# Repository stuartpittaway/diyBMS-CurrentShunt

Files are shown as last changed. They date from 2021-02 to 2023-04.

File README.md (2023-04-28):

# diyBMS Current Monitor

Isolated current, voltage and amp hour counting monitor for battery banks up to 85 volt.

Designed for use with the diyBMS controller, although can be operated standalone using RS485 and MODBUS

The MODBUS register list is [here](./Code/diybmsCurrentShunt/MODBUS%20Registers.md)

# Videos on how to use and build

[YouTube playlist](https://youtube.com/playlist?list=PLHhwQCDPuRcZW3u0jJucsiCCsUbNbMy-c) for DIYBMS videos

# Support

If you find the BMS useful, please consider buying me a beer, check out Patron for more information

https://patreon.com/StuartP

Forum:
https://community.openenergymonitor.org/c/hardware/diybms/53

# HARDWARE

This repository contains the hardware designs, generally in KiCad format.  Unless you are changing the design, you don't need to use/install KiCad, just use the premade files.

The GERBER files are in the [export folder](CurrentShuntCircuit/export), along with the files for JLCPCB assembly service.  You need to request the BOTTOM of the board to be assembled!!

* [current_monitor_gerbers.zip](../../raw/master/CurrentShuntCircuit/export/current_monitor_gerbers.zip)
* [CurrentShuntCircuit_bom_jlc.csv](../../raw/master/CurrentShuntCircuit/export/CurrentShuntCircuit_bom_jlc.csv)
* [CurrentShuntCircuit_cpl_jlc.csv](../../raw/master/CurrentShuntCircuit/export/CurrentShuntCircuit_cpl_jlc.csv)

If you use this coupon code when you place a JLCPCB order

JLC-Stuart

and this link

https://jlcpcb.com/RSZ

you will get a discount and I get a very small amount of credit for every 30 orders, which helps to support the cost of prototyping new designs and adding new features.

Gerber and BOM files are automatically generated when changes are made to the design and pushed into GITHUB.

The bill of materials (BOM) is [here](./CurrentShuntCircuit/export/CurrentShuntCircuit-bom.csv)

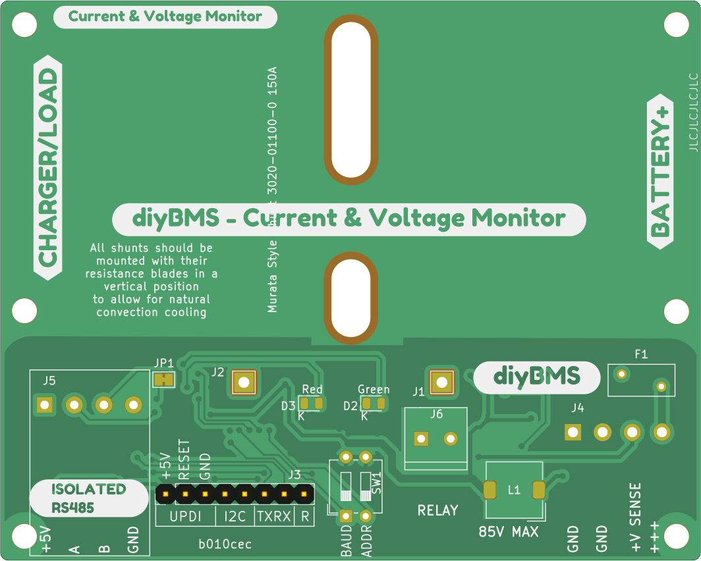
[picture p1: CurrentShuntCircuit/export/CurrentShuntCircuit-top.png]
top


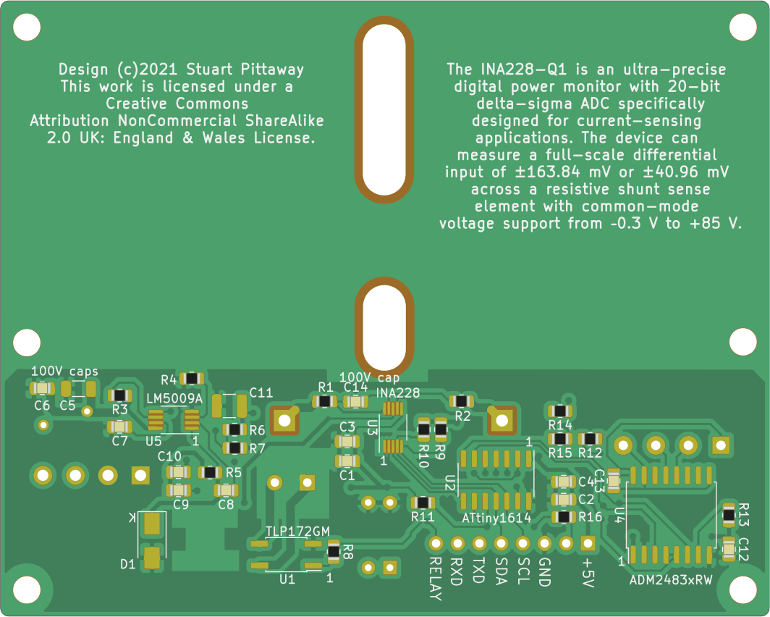
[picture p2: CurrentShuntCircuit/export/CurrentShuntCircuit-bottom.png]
bottom


## Texas Instruments

### INA228 (current sensor)
https://www.ti.com/product/INA228

### LM5009A (voltage regulator)
https://www.ti.com/product/LM5009A

## diyBMS Controller Changes

You need to add a "blob" of solder across solder bridge JP4 on the DIYBMS controller to enable RS485 termination resistor.

# SHUNT

The design is based on 50mV shunts, such as the Murata range

* 3020-01100-0 [150A](https://uk.farnell.com/murata-power-solutions/3020-01100-0/dc-shunt-150a-0-05v-screw/dp/2932602)
* 3020-0110X-0 [200A](https://uk.rs-online.com/web/p/shunts/8103277/) or [500A](https://uk.rs-online.com/web/p/shunts/8233570/)

technically, any 50mV shunt can be used, but the PCB is drilled specifically for the footprints of these devices.

Larger rating shunts will work, but won't fit onto the PCB

## PICKING THE CORRECT SHUNT 

Always pick a shunt at least 25% higher rating than you expect your maximum current load to be.

The INA chip uses 40.96mV maximum shunt voltage, so 50mV shunts are ideal for this range.

The maximum shunt current reading is calculated by this formula:

"Total shunt amp rating" * (40.96 / "Shunt mV scale")

For example a 200amp/50mV shunt:

200 * (40.96 / 50) = 163.84amp maximum reading.

# CODE/FIRMWARE



The board uses an ATTINY1614 chip, this requires an UPDI style of programmer, you can use an old Arduino style board to do this.  Take a look at [this](https://www.hackster.io/john-bradnam/create-your-own-updi-programmer-1e55f1) or [this](https://github.com/SpenceKonde/AVR-Guidance/blob/master/UPDI/jtag2updi.md).

Source code is located in the [Code](Code) folder, and requires PLATFORM.IO to compile.

Precompiled versions are available in the [releases](https://github.com/stuartpittaway/diyBMS-CurrentShunt/releases) page.  You use AVRDUDE to program these to the ATTINY chip using an UPDI programmer.

## Programming ATTINY1614

Use the file diyBMSCurrentMonitor_ATtiny1614.hex from the releases section.  This is precompiled for you, so after this all you need to do is use AVRDUDE to program the device.

AVRDUDE can be downloaded from [here](http://savannah.nongnu.org/projects/avrdude)

Change "COM8" to match your environment.  

```
avrdude -v -p attiny1614 -C avrdude.conf -c jtag2updi -b 115200 -P "COM8" -U flash:w:diyBMSCurrentMonitor_ATtiny1614.hex:i
```

# WARNING

This is a DIY product/solution so don’t use this for safety critical systems or in any situation where there could be a risk to life.  

There is no warranty, it may not work as expected or at all.

The use of this project is done so entirely at your own risk.  It may involve electrical voltages which could kill - if in doubt, seek help.

The use of this project may not be compliant with local laws or regulations - if in doubt, seek help.

# License

This work is licensed under a Creative Commons Attribution-NonCommercial-ShareAlike 2.0 UK: England & Wales License.

https://creativecommons.org/licenses/by-nc-sa/2.0/uk/

You are free to:
* Share — copy and redistribute the material in any medium or format
* Adapt — remix, transform, and build upon the material
The licensor cannot revoke these freedoms as long as you follow the license terms.

Under the following terms:
* Attribution — You must give appropriate credit, provide a link to the license, and indicate if changes were made. You may do so in any reasonable manner, but not in any way that suggests the licensor endorses you or your use.
* Non-Commercial — You may not use the material for commercial purposes.
* ShareAlike — If you remix, transform, or build upon the material, you must distribute your contributions under the same license as the original.
* No additional restrictions — You may not apply legal terms or technological measures that legally restrict others from doing anything the license permits.

Notices:
You do not have to comply with the license for elements of the material in the public domain or where your use is permitted by an applicable exception or limitation.

No warranties are given. The license may not give you all of the permissions necessary for your intended use. For example, other rights such as publicity, privacy, or moral rights may limit how you use the material.

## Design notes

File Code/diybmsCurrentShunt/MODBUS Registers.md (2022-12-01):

# Holding Registers (command 3)

Returns 16 bit word value for the following configuration items.  Some items are split over two registers and will need to recombined before use.
For valid results you must read both registers as part of the same request, otherwise invalid/corrupt data will be returned.

All registers are read only, unless also specified in "Write Registers" later on

|Register|Description|
|---|---|
|40001|Voltage (4 byte double)
|40002|Voltage
|40003|Current (4 byte double)
|40004|Current
|40005|milliamphour_out (4 byte unsigned long uint32_t)
|40006|milliamphour_out
|40007|milliamphour_in (4 byte  unsigned long uint32_t)
|40008|milliamphour_in
|40009|temperature (signed int16)
|40010|Various status flags (see below)
|40011|Power (4 byte double)
|40012|Power
|40013|Daily milliamphour_out (4 byte unsigned long uint32_t)
|40014|Daily milliamphour_out (4 byte unsigned long uint32_t)
|40015|Daily milliamphour_in (4 byte  unsigned long uint32_t)
|40016|Daily milliamphour_in
|40017|shunt_resistance (4 byte double)
|40018|shunt_resistance
|40019|shunt_max_current  (unsigned int16)
|40020|shunt_millivolt  (unsigned int16)
|40021|Battery Capacity (ah)  (unsigned int16)
|40022|Fully charged voltage (4 byte double)
|40023|Fully charged voltage
|40024|Tail current (Amps) (4 byte double)
|40025|Tail current (Amps)
|40026|Charge efficiency factor % (unsigned int16) (scale x100 eg. 10000 = 100.00%, 9561 = 95.61%)
|40027|State of charge % (unsigned int16) (scale x100 eg. 10000 = 100.00%, 8012 = 80.12%, 100 = 1.00%)
|40028|INA_REGISTER::SHUNT_CAL (unsigned int16)
|40029|Temperature limit (signed int16)
|40030|Bus Overvoltage (overvoltage protection)(4 byte double)
|40031|Bus Overvoltage (overvoltage protection)
|40032|BusUnderVolt (4 byte double)
|40033|BusUnderVolt
|40034|Shunt Over Voltage Limit (current limit) (4 byte double)
|40035|Shunt Over Voltage Limit (current limit) 
|40036|Shunt UNDER Voltage Limit (under current limit) (4 byte double)
|40037|Shunt UNDER Voltage Limit (under current limit)
|40038|Shunt Over POWER LIMIT (4 byte double)
|40039|Shunt Over POWER LIMIT
|40040|Shunt Temperature Coefficient (SHUNT_TEMPCO) (unsigned int16)
|40041|INAXXX chip model number (should always be 0x0228)
|40042|GITHUB version
|40043|GITHUB version
|40044|COMPILE_DATE_TIME_EPOCH
|40045|COMPILE_DATE_TIME_EPOCH
|40046|Watchdog timer trigger count (like error counter)(unsigned int16)
|40047|DEBUG CONFIG (unsigned int16)
|40048|DEBUG ADC_CONFIG (unsigned int16)
|40049|DEBUG SHUNT_CAL (unsigned int16)
|40050|DEBUG SHUNT_TEMPCO
|40051|DEBUG DIAG_ALRT
|40052|DEBUG SOVL
|40053|DEBUG SUVL
|40054|DEBUG BOVL
|40055|DEBUG BUVL
|40056|DEBUG TEMP_LIMIT
|40057|DEBUG PWR_LIMIT
|40058|DEBUG DIETEMP

# 0x16 Write Multiple Registers

|Register|Description|Example|
|---|---|---|
|40010|Watchdog timer trigger count (like error counter) (unsigned int16)|
|40013|Daily milliamphour_out/reset to zero
|40014|Daily milliamphour_out/reset to zero
|40015|Daily milliamphour_in/reset to zero
|40016|Daily milliamphour_in/reset to zero
|40019|shunt_max_current  (unsigned int16) |e.g. 150
|40020|shunt_millivolt  (unsigned int16) |e.g. 50
|40021/40022|Battery Capacity (ah)  (unsigned int16)
|40023/40024|Fully charged voltage
|40025|Tail current (Amps)
|40026|Charge efficiency factor % (unsigned int16) (scale x100 eg. 10000 = 100.00%, 9561 = 95.61%)
|40028|SHUNT_CAL (unsigned int16) **
|40029|Temperature limit (signed int16)|degrees C)
|40030/40031|Bus Overvoltage (overvoltage protection)(4 byte double)|Volts
|40032/40033|Bus Under Volt (4 byte double) |Volts
|40034/40035|Shunt Over Voltage Limit (current limit) (4 byte double)|Current
|40036/40037|Shunt UNDER Voltage Limit (under current limit) (4 byte double)|Current
|40038/40039|Shunt Over POWER LIMIT (4 byte double)|Power

** For normal configuration, just set the shunt maximum current and millivolt registers.  Shunt_Cal is calculated as needed based on those values.  For fine tuning calibration, the SHUNT_CAL register can be written to/adjusted.  Once a register is set, it is stored in EEPROM and used when shunt is powered up.

# Bit values for Register 40017 (status flags)

Returns a BIT value (on/off) for the following configuration items:

(First byte)
|Bit|Description|Read write|
|---|---|---|
16|TMPOL|Read only
15|SHNTOL|Read only
14|SHNTUL|Read only
13|BUSOL|Read only
12|BUSUL|Read only
11|POL|Read only
10|Temperature compensation enabled|Read write
9|ADC Range 0=±163.84 mV, 1=±40.96 mV (only 40.96mV supported by diyBMS)|Read only

(Second byte)
|Bit|Description|Read write|
|---|---|---|
8|Relay Trigger on TMPOL|Read write
7|Relay Trigger on SHNTOL|Read write
6|Relay Trigger on SHNTUL|Read write
5|Relay Trigger on BUSOL|Read write
4|Relay Trigger on BUSUL|Read write
3|Relay Trigger on POL|Read write
2|Existing Relay state (0=off)|Read write
1|Factory reset bit (always 0 when read)|Read write

Registers 1 to 6 indicate the current alert state of the INA228 chip, zero means not alerted.  The RED LED will light when any of the alert states are non-zero.

Registers 9 to 14 control which alerts will trigger the relay to turn on.  Value of 1 means the alert is active/enabled.

Register 15 returns the current relay state (and allows the relay to be manually controlled - TBC)

Register 16 always returns zero when read (set to 1 to perform a factory reset on the monitor, returning all values to defaults - TBC)

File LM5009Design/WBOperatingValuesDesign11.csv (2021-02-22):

Name | Value | Category | Description
D1 Pd | 29.17 mW | Diode | Output Diode Power Dissipation
Vout | 5 V | System Information | Operational Output Voltage
IC Tolerance | 50 mV | IC | IC Feedback Tolerance
Cin IRMS | 11.93 mA | Capacitor | Input capacitor RMS ripple current
Cin Pd | 504.32 nW | Capacitor | Input capacitor power dissipation
Cout IRMS | 26.37 mA | Capacitor | Output capacitor RMS ripple current
Cout Pd | 2.11 µW | Capacitor | Output capacitor power dissipation
Duty Cycle | 6.06% | System Information | Duty cycle
Frequency | 53.09 kHz | System Information | Switching frequency
IC Tj | 62.2 °C | IC | IC junction temperature
ICThetaJA | 40 °C/W | IC | IC junction-to-ambient thermal resistance
L Ipp | 91.33 mA | Inductor | Peak-to-peak inductor ripple current
L Pd | 7.13 mW | Inductor | Inductor power dissipation
IC Pd | 55.06 mW | IC | IC power dissipation
Pout | 250 mW | System Information | Total output power
Iin Avg | 3.67 mA | IC | Average input current
IC Ipk | 95.67 mA | IC | Peak switch current in IC
Mode | CCM | System Information | Conduction Mode
Vout p-p | 277.38 µV | System Information | Peak-to-peak output ripple voltage
M Vds Act | 15.52 mV | Mosfet | Voltage drop across the MosFET
M Irms | 12.31 mA | Mosfet | MOSFET RMS current
Total Pd | 91.36 mW | Power | Total Power Dissipation
Efficiency | 73.2% | System Information | Steady state efficiency
FootPrint | NA | System Information | Total Foot Print Area of BOM components
D1 Pd | 29.17 mW | Power | Output Diode Power Dissipation
Vin | 85 V | System Information | Vin operating point
Iout | 50 mA | System Information | Iout operating point
Cin Pd | 504.32 nW | Power | Input capacitor power dissipation
Cout Pd | 2.11 µW | Power | Output capacitor power dissipation
L Pd | 7.13 mW | Power | Inductor power dissipation
IC Pd | 55.06 mW | Power | IC power dissipation
BOM Count | 6 | System Information | Total Design BOM count
Vout Actual | 5 V | System Information | Vout Actual calculated based on selected voltage divider resistors
Vout Tolerance | 3.03% | System Information | Vout Tolerance based on IC Tolerance (no load) and voltage divider resistors if applicable
Total BOM | NA | System Information | Total BOM Cost

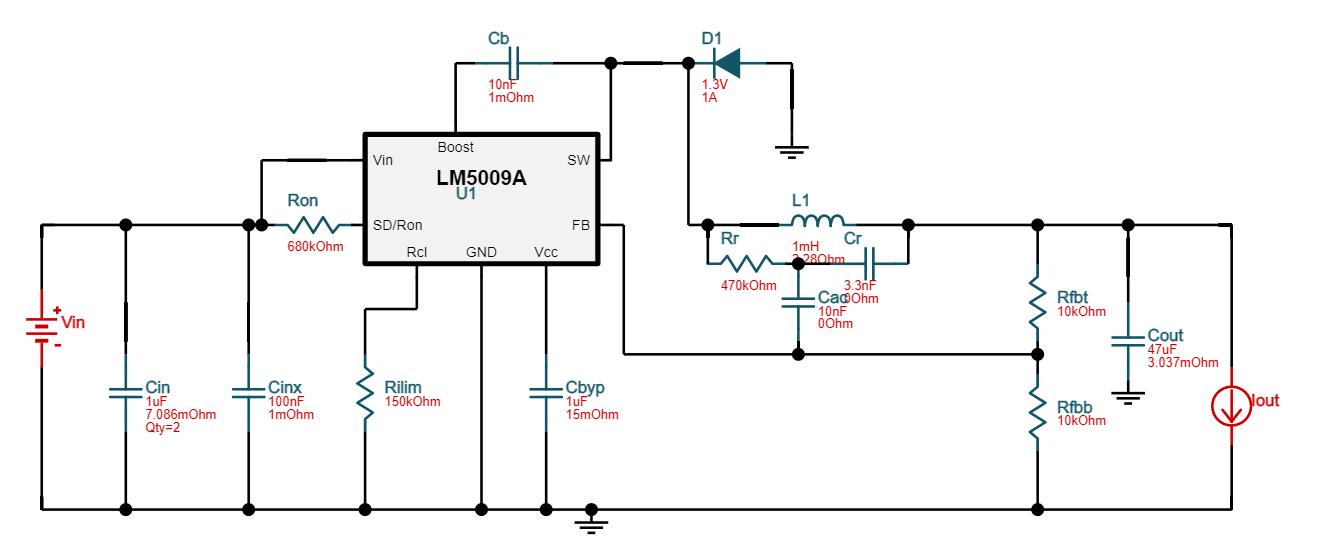
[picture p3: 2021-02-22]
LM5009Design/circuit.png

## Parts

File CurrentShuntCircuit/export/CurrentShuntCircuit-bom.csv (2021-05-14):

Row | Description | Part | References | Value | Footprint | Quantity Per PCB | Status | Datasheet | PartNumber | LCSCStockCode | JLCPCBRotation | JLC
1 | Unpolarized capacitor | C | C10 | 3.3nF | C_0805_2012Metric | 1 |  | ~ | CL21B332KBANNNC | C53175
2 | Unpolarized capacitor | C | C8 C9 | 10nF | C_0805_2012Metric | 2 |  | ~ | CL21B103KBANNNC | C1710
3 | Unpolarized capacitor | C | C3 C4 C12 C13 | 100nF | C_0805_2012Metric | 4 |  |  | CC0805KRX7R9BB104 | C49678
4 | Unpolarized capacitor | C | C1 C2 C7 | 1uF | C_0805_2012Metric | 3 |  | ~ | CL21B105KBFNNNE | C28323
5 | Unpolarized capacitor | C | C5 | 1uF | C_1206_3216Metric | 1 |  | https://datasheet.lcsc.com/szlcsc/Samsung-Electro-Mechanics-CL31B105KCHNNNE_C13832.pdf | CL31B105KCHNNNE | C13832
6 | Unpolarized capacitor | C | C11 | 47uF | C_1210_3225Metric | 1 |  | https://search.murata.co.jp/Ceramy/image/img/A01X/G101/ENG/GRM32ER61C476KE15-01.pdf | GRM32ER61C476KE15L | C77101
7 | Unpolarized capacitor | C | C6 C14 | 100nF 100V | C_0805_2012Metric | 2 |  | https://datasheet.lcsc.com/szlcsc/2008131833_KEMET-C0805C104K1RECAUTO_C696367.pdf | C0805C104K1RECAUTO | C696367
8 | Schottky diode | D_Schottky | D1 | 400V 1A 1.3V @ 1A 150ns SMA | D_SMA | 1 |  | https://datasheet.lcsc.com/szlcsc/1810170425_Diodes-Incorporated-RS1G-13-F_C85103.pdf | RS1G-13-F | C85103
9 | Light emitting diode | LED | D2 | GREEN | LED_0805_2012Metric | 1 |  | ~ |  | C2297
10 | Light emitting diode | LED | D3 | RED | LED_0805_2012Metric | 1 |  | ~ |  | C84256
11 | Resettable fuse, polymeric positive temperature coefficient | Polyfuse | F1 | Through Hole PTC | Fuse_BelFuse_0ZRE0005FF_L8.3mm_W3.8mm | 1 |  | https://datasheet.lcsc.com/szlcsc/1912111437_Jinrui-Electronic-Materials-Co-JK250-120U_C369130.pdf | JK250-100U | C2680606
12 | Generic connector, single row, 01x08, script generated (kicad-library-utils/schlib/autogen/connector/) | Conn_01x08_Male | J3 | Debug/UPDI | PinHeader_1x08_P2.54mm_Vertical | 1 |  | ~
13 | Generic screw terminal, single row, 01x02, script generated (kicad-library-utils/schlib/autogen/connector/) | Screw_Terminal_01x02 | J6 | ScrewTerminal | Terminal-Block_3.81_2P-LCSC_C395878 | 1 |  | https://datasheet.lcsc.com/szlcsc/1912111437_DIBO-DB125-3-81-2P-GN_C395878.pdf |  | C395878
14 | Generic screw terminal, single row, 01x04, script generated (kicad-library-utils/schlib/autogen/connector/) | Screw_Terminal_01x04 | J4 J5 | Screw_Terminal_01x04 | Terminal-Block_3.81_4P_LCSC_C395880 | 2 |  |  |  | C395880
15 | Inductor | L | L1 | 1mH | L_TDK_SLF7045 | 1 |  |  | SLF7045T-102MR14-PF | C91523
16 | Resistor | R | R1 R2 | 10R | R_0805_2012Metric | 2 |  | ~ | 0805W8F100JT5E | C17415
17 | Resistor | R | R12 | 120R | R_0805_2012Metric | 1 |  | ~ | 0805W8F1200T5E | C17437
18 | Resistor | R | R8 R14 R15 | 330R | R_0805_2012Metric | 3 |  | ~ | 0805W8F3300T5E | C17630
19 | Resistor | R | R16 | 470R | R_0805_2012Metric | 1 |  | ~ | 0805W8F4700T5E | C17710
20 | Resistor | R | R9 R10 | 4k7 | R_0805_2012Metric | 2 |  | ~ | 0805W8F4701T5E | C17673
21 | Resistor | R | R6 R7 R13 | 10k | R_0805_2012Metric | 3 |  | ~ | 0805W8F1002T5E | C17414
22 | Resistor | R | R11 | 100K | R_0805_2012Metric | 1 |  | ~ | 0805W8F1003T5E | C17407
23 | Resistor | R | R4 | 150k | R_0805_2012Metric | 1 |  | ~ | 0805W8F1503T5E | C17470
24 | Resistor | R | R5 | 470k | R_0805_2012Metric | 1 |  | ~ | 0805W8F4703T5E | C17709
25 | Resistor | R | R3 | 680k | R_0805_2012Metric | 1 |  | ~ | 0805W8F6803T5E | C17797
26 | 2x DIP Switch, Single Pole Single Throw (SPST) switch, small symbol | SW_DIP_x02 | SW1 | SW_DIP_x02 | SW_DIP_SPSTx02_Slide_6.7x6.64mm_W7.62mm_P2.54mm_LowProfile | 1 |  | https://datasheet.lcsc.com/szlcsc/2004251705_Korean-Hroparts-Elec-DS-02BP_C458081.pdf |  | C458081
27 | Isolated RS485/RS422 Transceiver, Half-Duplex, 500kbps, SOIC-16W | ADM2483xRW | U4 | ADM2483xRW | SOIC-16W_7.5x10.3mm_P1.27mm | 1 |  | https://www.analog.com/media/en/technical-documentation/data-sheets/adm2483.pdf | ADM2483BRWZ-REEL | C386280
28 | 20MHz, 16kB Flash, 2kB SRAM, 256B EEPROM, SOIC-14 | ATtiny1614-SS | U2 | ATtiny1614-SS | SOIC-14_3.9x8.7mm_P1.27mm | 1 |  | http://ww1.microchip.com/downloads/en/DeviceDoc/ATtiny1614-data-sheet-40001995A.pdf | ATTINY1614-SSNR | C481364
29 | High-Side or Low-Side Measurement, Bi-Directional Current and Power Monitor (0-36V) with I2C Compatible Interface, VSSOP-10 | INA226 | U3 | INA228 | VSSOP-10_3x3mm_P0.5mm | 1 |  | https://www.ti.com/lit/ds/symlink/ina228.pdf | INA228
30 | LM5009A 100-V, 150-mA Constant ON-Time Buck Switching Regulator | LM5009A | U5 | LM5009A | MSOP-8_3x3mm_P0.65mm | 1 |  | https://www.ti.com/lit/ds/symlink/lm5009a.pdf | LM5009AMMX/NOPB | C477978
31 | Form A, Solid State Relay (Photo MOSFET) 60V, 0.2A, 10Ohm, SO-4 | ASSR-1218 | U1 | TLP172GM | SO-4_4.4x3.6mm_P2.54mm | 1 |  | https://datasheet.lcsc.com/szlcsc/TOSHIBA-TLP172GM-TPL-E-O_C261926.pdf | TLP172GM | C261926

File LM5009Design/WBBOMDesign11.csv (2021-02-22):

Part | Manufacturer | Part Number | Quantity | Price ($) | Footprint (mm²) | Description
Cout | MuRata | GRM32ER61C476KE15L | 1 | 0.38 | 14.7 | Cap: 47 µF Total Derated Cap: 32 µF VDC: 16 V ESR: 3.04 mΩ Package: 1210
Rr | CUSTOM | CUSTOM | 1 | NA | NA | Resistance: 470 kΩ Tolerance: 1.0% Power: 250 mW
Cr | AVX | 08053A332JAT2A | 1 | 0.07 | 6.75 | Cap: 3.3 nF Total Derated Cap: 3.3 nF VDC: 25 V ESR: 0 Ω Package: 0805
Cac | Samsung Electro-Mechanics | CL32C103JBFNNNE | 1 | 0.79 | 14.7 | Cap: 10 nF Total Derated Cap: 10 nF VDC: 5 V ESR: 0 Ω Package: 1210
Rfbb | Yageo | RC0201FR-0710KL | 1 | 0.01 | 2.08 | Resistance: 10 kΩ Tolerance: 1.0% Power: 50 mW
Ron | CUSTOM | CUSTOM | 1 | NA | NA | Resistance: 680 kΩ Tolerance: 1.0% Power: 50 mW
L1 | TDK | SLF7045T-102MR14-PF | 1 | 0.45 | 81 | L: 1 mH DCR: 2.28 Ω IDC: 140 mA
Cin | MuRata | GRM55DR72E105KW01L | 2 | 0.54 | 53.9 | Cap: 1 µF Total Derated Cap: 1.2 µF VDC: 250 V ESR: 7.09 mΩ Package: 2220
U1 | Texas Instruments | LM5009AMM/NOPB | 1 | 0.968 | 23.6
Rilim | CUSTOM | CUSTOM | 1 | NA | NA | Resistance: 150 kΩ Tolerance: 1.0% Power: 50 mW
Rfbt | Yageo | RC0201FR-0710KL | 1 | 0.01 | 2.08 | Resistance: 10 kΩ Tolerance: 1.0% Power: 50 mW
Cinx | TDK | C2012X7T2E104K125AA | 1 | 0.06 | 6.75 | Cap: 100 nF Total Derated Cap: 56 nF VDC: 250 V ESR: 1 mΩ Package: 0805
D1 | Diodes Inc. | RS1G-13-F | 1 | 0.07 | 37.34 | Type: Ultrafast VRRM: 400 V Io: 1 A
Cbyp | Kemet | C0805C105K4RACTU | 1 | 0.02 | 6.75 | Cap: 1 µF Total Derated Cap: 1 µF VDC: 16 V ESR: 15 mΩ Package: 0805
Cb | MuRata | GRM155R71H103KA88D | 1 | 0.01 | 3 | Cap: 10 nF Total Derated Cap: 9.5 nF VDC: 50 V ESR: 1 mΩ Package: 0402

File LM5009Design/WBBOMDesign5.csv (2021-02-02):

Part | Manufacturer | Part Number | Quantity | Price ($) | Footprint (mm²) | Description
Cout | MuRata | GRM21BR60J226ME39L | 2 | 0.1 | 6.75 | Cap: 22 µF Total Derated Cap: 23 µF VDC: 6.3 V ESR: 9 mΩ Package: 0805
Rr | Vishay-Dale | CRCW0805715KFKEA | 1 | 0.01 | 6.75 | Resistance: 715 kΩ Tolerance: 1.0% Power: 125 mW
Cr | Kemet | C0603C302K5GACTU | 1 | 0.09 | 4.68 | Cap: 3 nF Total Derated Cap: 3 nF VDC: 50 V ESR: 0 Ω Package: 0603
Cac | Samsung Electro-Mechanics | CL32C103JBFNNNE | 1 | 0.79 | 14.7 | Cap: 10 nF Total Derated Cap: 10 nF VDC: 5 V ESR: 0 Ω Package: 1210
Rfbb | Vishay-Dale | CRCW040231K6FKED | 1 | 0.01 | 3 | Resistance: 31.6 kΩ Tolerance: 1.0% Power: 63 mW
Ron | Yageo | RC0201FR-7D562KL | 1 | 0.01 | 2.08 | Resistance: 562 kΩ Tolerance: 1.0% Power: 50 mW
L1 | TDK | SLF7045T-102MR14-PF | 1 | 0.45 | 81 | L: 1 mH DCR: 2.28 Ω IDC: 140 mA
Cin | TDK | C3216X7R2A105M160AA | 1 | 0.12 | 10.92 | Cap: 1 µF Total Derated Cap: 270 nF VDC: 100 V ESR: 7.5 mΩ Package: 1206
U1 | Texas Instruments | LM5009MM/NOPB | 1 | 0.968 | 23.6
Rilim | Yageo | RC0201FR-07133KL | 1 | 0.01 | 2.08 | Resistance: 133 kΩ Tolerance: 1.0% Power: 50 mW
Rfbt | Yageo | RC0201FR-0710KL | 1 | 0.01 | 2.08 | Resistance: 10 kΩ Tolerance: 1.0% Power: 50 mW
Cinx | TDK | C2012X7T2E104K125AA | 1 | 0.06 | 6.75 | Cap: 100 nF Total Derated Cap: 60 nF VDC: 250 V ESR: 1 mΩ Package: 0805
D1 | Diodes Inc. | B1100LB-13-F | 1 | 0.09 | 44.16 | Type: Schottky VRRM: 100 V Io: 1 A
Cbyp | Kemet | C0805C105K4RACTU | 1 | 0.02 | 6.75 | Cap: 1 µF Total Derated Cap: 1 µF VDC: 16 V ESR: 15 mΩ Package: 0805
Cb | MuRata | GRM155R71H103KA88D | 1 | 0.01 | 3 | Cap: 10 nF Total Derated Cap: 9.5 nF VDC: 50 V ESR: 1 mΩ Package: 0402

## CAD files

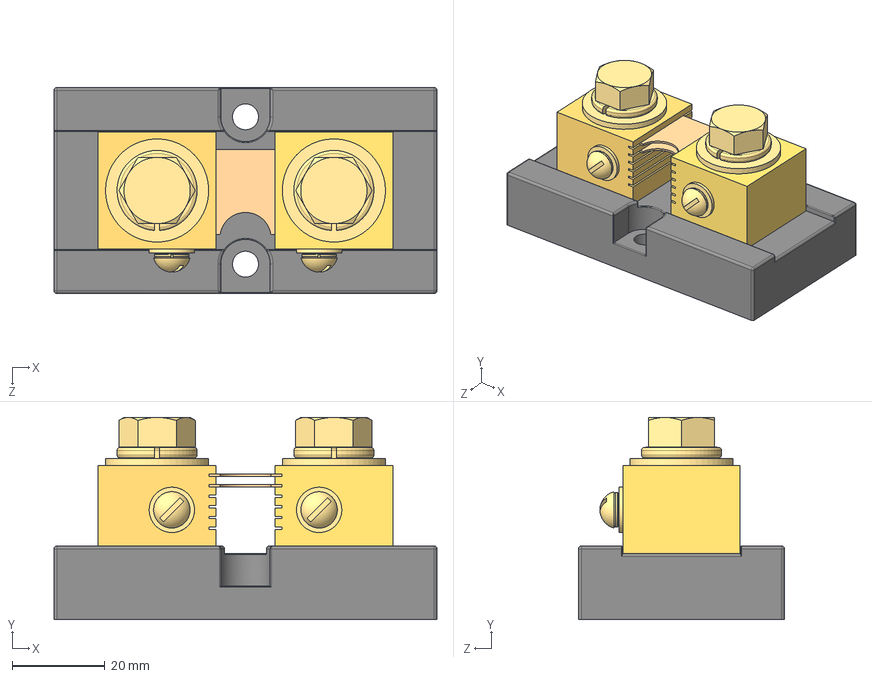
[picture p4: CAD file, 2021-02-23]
CurrentShuntCircuit/mps_dpm_dc_shunt_200amps.step
82.6 x 43.6 x 44.5 mm

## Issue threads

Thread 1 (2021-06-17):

add an option form a 300A 50mV Shunt

chapulino, 2021-06-17:
It would be interesting to have an intermediate option between the 200A and 500A Shunts.
That is why I suggest that the selection of a 300A sunt be considered, which would be an intermediate point

SergioRius, 2021-06-18:
I would second this. As the recommended fuse by Victron in their Multiplus2 5000 is a 200A one, someone would expect a 200A shunt to be fairly tight and depending on the provider and quality, not enough.
Is this range simply programmed in the firmware or it depends on a boards component?

stuartpittaway, 2021-06-18:
Purely software controlled, so happy to add the other options

SergioRius, 2021-06-18:
> Purely software controlled, so happy to add the other options

We've been looking at the code this afternoon and saw that it nicely accepts the shunt capacity on the 18th address.

And the following link as been moving around as an cheap supply of shunts for testing. The nice thing is that it has a selection of device capacity:

https://a.aliexpress.com/_vSp8LH

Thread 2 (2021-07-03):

PCB does not fit 200A shunt

magpern, 2021-07-03:
The 200A shunt does not fit on the pcb.
The holes on the shunt is of by about half a hole.
And the shunt covers the pcb corner holes.

This is the shunt, I think it is the correct one.
https://www.digikey.se/short/bd507d49

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

stuartpittaway, 2021-07-04:
Ok, I'll update the PCB. There are no components/traces on that side of the board, so you should be safe to drill a new hole.

stuartpittaway, 2021-07-06:
Can I ask you to confirm these measurements against the real shunt you have?

It should be 82.5mm by 44.4mm

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

magpern, 2021-07-06:
I finally found my slide measure tool. My son tidied the garage.. garage looks nice.. tools are a little random.

The outer dimensions of the actual shunt (200A) is pretty must correct.
But the hole placement is not.
I used a digital slide measure and got the holes to 5.3mm, which is also proven by the other measurements, hole-side to hole-side, and wall to hole. I measured several times and got almost the same numbers.

A = 3.7 mm
B = 26.6 mm
C = 37.2 mm

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

stuartpittaway, 2021-07-07:
Thanks - as I thought the physical device doesn't match the data sheet!

I've modified the PCB to add another 5mm to the slot so it should now fit.  I'm doubtful that it will still fit inside the green DIN rail mount now though.

Closed 2021-07-07.

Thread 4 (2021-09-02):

Over/under current limit not settable

magpern, 2021-09-02:
My system can pass over 180 amps. But I cannot set the over/under current limits to more than 127, and if I do, they become -127.
127+127 = 0xFF = one byte. Is the field too small?

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

stuartpittaway, 2021-09-02:
What are the shunt amps and MV rating? That determines the maximum.

magpern, 2021-09-02:
> What are the shunt amps and MV rating? That determines the maximum.
>
> Those settings only control the relay on the shunt itself, not the controller.

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

stuartpittaway, 2021-09-02:
Ok, the maximum should be higher than that. I'll take a look at the code.

The max should be

Total shunt amp rating * (40.96/50mV)

stuartpittaway, 2021-09-03:
Ok, in which case this is correct.

This is how the INA228 chip works.  given you are trying to use 180amps through a 200amp shunt, I believe the shunt is under rated.

You should have a shunt with at least 25% overhead - or about 225amps (probably 250amp shunt would have been better).

magpern, 2021-09-03:
Highly unlikely that I personally would use 163 amps, I will be around 130 amps max. But regardless. If you type 180 in the field, it accepts it, but changes it to some negative number instead.

stuartpittaway, 2021-09-03:
Ok, the controller doesn't calculate what is a correct or incorrect value, its simply passing it to the code on the current monitor board, and that then accepts/rejects the value and applies a default if its out of range.

I probably need to make that a little clearer on the screen.

The negative/positive numbers relate to the different limits you can have for charge or discharge.

The "Over current limit" is positive (used for discharge of the battery), the "Under current limit" will be negative (used for charging the battery).

Normally most people will set these to be the same - or just ignore that section completely if they are not using the relay on the current monitor board.

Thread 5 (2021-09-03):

SoC not resetting

magpern, 2021-09-03:
I have 55V set as fully charged voltage. And tail to 3 amps. It hit 55V, stayed around this voltage for 1 hour. Now inverter is going into "Float" at 54.50V. SoC is still 105%

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

And as an extra feature. A field to manually set a presumed SoC

stuartpittaway, 2021-09-03:
Ok, the current is negative which means you are discharging from the battery.

The reset only occurs when the charging "tail current" (positive value) is reached.  So you would need the voltage to go over 55V (at the shunt voltage) and the charging current to be below 3amps for over 3 minutes.

magpern, 2021-09-03:
At 10:53 it hit 55V (but setting was 55.50V)
I changed it to 55V at this time.

It was arount 55V +-50mV for close to an hour, and was below 5 amps several times.
I think it could be the changing of the voltage value from 55.5V to 55V, while it was above 55V.

Attached is the voltage curve. Red arrow is when it hit 55V.

I also think 5 amps is too low for me, I will change that. In Victron you don't specify the amp, you set a percent value. I think I have 2 or 3% in my SmartShunt. Ant it is a percentage of the Ah of the battery. So I'll bump it up 10 or 15 amps.

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

stuartpittaway, 2021-09-03:
Might be worth logging the shunt monitor values from the diyBMS so you can see what it thinks is going on.

magpern, 2021-09-03:
> Might be worth logging the shunt monitor values from the diyBMS so you can see what it thinks is going on.

I will do that and report back. I have an influxdb in home assistant. I will try and get diyBMS to report to it

chapulino, 2021-11-07:
Magpern,  could you solve it, am I in a similar situation? Although in my case the parameters are a little different because it is a larger battery (600A) so the tail curren is at 12A (Victron recommends for this value in lifepo4 batteries, 2% of the battery capacity)
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

chapulino, 2021-11-08:
I finally got it to synchronize at 100% it was silly, it had a maximum voltage value, now in all the places it is 54.4V and it is going great. Never with Victron have I had a 100% load so stable and with so little deviation in the cell voltage. As the maximum approaches, the current is gradually reduced until it reaches 100% load, the operation in my opinion is impeccable,
TIP I have no difference between maximum voltage and float (I think that step is reminiscent of lead batteries

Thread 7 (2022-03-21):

Sourcing parts for CurrentShunt and Victron Integration

allanlind, 2022-03-21:
Hi Stuart, I have trouble sourcing some of the parts for the CurrentShunt and wondered if you might have ideas where to buy.
ADM2483BRWZ, ATTINY1614-SSNR, LM5009AMMX/NOPB, INA228AIDGSR are not available on Mouser or Digikey.
The ADM and ATTINY I managed to find on Ali Express or Ebay. But the LM5009 and INA228 are a problem.
I only need enough parts to build 2 current shunt boards. Do you by chance have any extras I can buy?

The reason for building the shunt is I cannot get the diyBMS Controller to work properly with the Victron GX inverter. I was hoping the problem would go away if I added the CurrentShunt to report the current flow in/out of the battery bank. Somehow the Victron is not working as it should in ESS mode.
Trying to keep grid at 0 is impossible as Clouds come over. And you can see the battery is not showing Current and charge level.
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

 I have Victron DVCC enabled so Victron gets its voltage from diyBMS controller but I have SCS (Shared Current Sense) turned off.
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

What happens is I have to manually adjust Grid Setpoint +/- 600W depending on house load and solar output.
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

I asked Victron for support and they said they will not support me as I am using an unsupported battery.

I figured if I have the CurrentShunt connected I can enable SCS.

stuartpittaway, 2022-03-22:
Hi.  Unfortunately I don't have any spares for the current shunt - as you mention, the parts are almost impossible to obtain at the moment.

I don't have much experience with Victron equipment - but I don't understand why you need to change the grid setpoint - I doubt DIYBMS would have any effect on this parameter.

Are you missing a current shunt/clamp to limit import/export ?

How can the Victron monitor the grid to determine if it needs to power the loads or not?

allanlind, 2022-03-22:
The Victron Multiplus has AC current monitoring on it’s input and output so i don’t see why it would need a shunt on AC. It should also be measuring the DC current into/out of battery. ESS is a Victron script you load in to the Multiplus which turns it into a smart energy storage system. Optimising battery life and minimising grid usage.
I am not sure how to explain this well. But all I want is to keep the grid set point at zero, so the Victron never uses power from the grid. Only feeds surplus back in when battery is fully charged. But the Victron won’t do this, it’s using power from the grid when my solar panels are working. Victron refuse to support this. The only way I can get the grid usage under control is to set the Grid Setpoint at -600W. But as the solar panels output varies on cloudy days the grid draw varies all over fhe show. Victron won’t support the inverter as I am using an unsupported battery. As I don’t have a supported battery I cannot troubleshoot. The only thing I can think is that I need to have shared current sense turned on and have diyBMS instruct the Victron the battery DC current.
Does this make sense?

stuartpittaway, 2022-03-22:
The current shunt on diybms will only tell you whats going in and out of the battery, but that won't give you the load on the house/grid.

allanlind, 2022-03-22:
I understand that. What I am trying to say is that the current shunt will tell diyBMS controller the instantaneous battery current , the +/-W setting and the battery charge %. The diyBMS controller will then pass these parameters on to the Victron via canbus. My guess is the Victron ESS script must have these readings for it to calculate grid current usage. Battery status may be critical for ESS to calculate whether to use power from the grid. It might think the battery is in an unhealthy state and needs to urgently use grid power. Just my guess. If you scroll up you will see my screen shot of the Victon console which is not displaying the Battery Watts, Amps, and % Charge. I think this is the problem. For some reason If I unplug the diyBMS controller from the canbus the Victron console shows the battery status as 100%. But then ESS goes into bypass mode.

tmichel-gh, 2023-02-22:
Hey Stuart,

if you're planning a redesign of the CurrentShunt board, what about switching from LM5009A Buck converter to an isolated 5VDC-5VDC-Converter and driving it through the 5V provided by the controller board (J5 Pin 1)? Also decreases the small energy amount consumed by the CurrentShunt itself, because only the measurement-voltage needs to be driven by the battery

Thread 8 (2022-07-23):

False current readings

red0909, 2022-07-23:
Hi, now i have detailed information about this issue.

so first
i have a 200A 60mV shunt
in discharge mode current readings are correct to -20mV shunt voltage below this voltage the current readings start to decrease and rise again randomly.

in charge mode this problem occures at 30mV over this voltage the current readings drop and rise again randomly.

additional the mV readings start to be inacurate for more than 30mV in charge and less than -20mV in discharge mode
if i stay within this limits all works fine.

you can use a small shunt like 50A 60mv to test this

thanks for your work.

stuartpittaway, 2022-07-24:
The INA228 chip has a scale of ±40.96 mV

If you are using a 200amp shunt, and driving 200A through it, it will be inaccurate, as the ADC will be saturated.

red0909, 2022-07-24:
does it mean -40 to 40mV or -20 to 20mV scale?
i thought the first.

stuartpittaway, 2022-07-24:
Yes the first.

red0909, 2022-07-24:
but the -40 to 40 does not work, maybe a hardware problem on my shunt pcb?
have you tested this range?

stuartpittaway, 2022-07-25:
How are you reading the mV value? Is this the value shown in the web page?

red0909, 2022-07-25:
i am reading it with a precise voltage meter. the readings correspond with the web page readings, if i stay in the range of 20 to -30 mV
i have 16s lifepo. at the moment limited to 100A charge and 65A discharge, i am waiting for a new shunt to be able to get 300A readings in future.
so if you can, please test this range in your shunt you can use a smaller one if you dont have the load for test.

stuartpittaway, 2023-01-25:
Hi @red0909, did you resolve this issue in the end?

Its probably worth updating the code on the current shunt as the SoC calculations have changed, along with the amp-hour counters.

I don't have a 60mV shunt to test what you are seeing in the previous tests.

red0909, 2023-01-25:
i have solved this issue with a bigger shunt 500a 50mv so that i stay in this -30/20mv range.
but i can test this new code with the 200a shunt again, i will let you know.

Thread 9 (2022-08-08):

Can save values even after review different problem ?

dudman, 2022-08-08:
The "Basic Settings" for current & Voltage Monitoring allow me to save, but then those settings are not displayed, seeming as though they havn't been saved. In the logs modbus90_date.csv I get empty values 2022-08-08 00:00:24,0,0.0000,0.0000,0,0,0.0000,0,0.0000,0

When I power up the shunt I get 4 green flashes, then regular red, I bought it pre wired/programmed from a guy on the forums along with a controller which is also work well. So I'm assuming its working right now ? The UPDI -> + gives a stead 5v....

stuartpittaway, 2022-08-08:
Might be worth checking you have the latest code on both controller and shunt

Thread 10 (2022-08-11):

100% soc calibration

red0909, 2022-08-11:
hi
can you add a rule of ignoring negative current up to -1A if the battery is over the fully charge voltage?

because my charge controller bounces in full status between 0,3 and -0,5A and the soc does not reset to 100%

thanks.

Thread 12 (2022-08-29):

Battery SOC goes under 0% and switch to 105%

buddhafragt, 2022-08-29:
I have the problem, when the battery reach 0% the SOC switch to 105%.
I think there is something wrong in the SOC calculation....

stuartpittaway, 2022-08-29:
It sounds like the battery capacity isn't set properly.

Can you send a screenshot of the current monitor page?

stuartpittaway, 2023-01-25:
The code to calculate the state of charge has been changed, can you try the latest version and report back?

Closed 2023-04-24.

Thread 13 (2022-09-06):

measurement inaccuracy?

MatthiasN73, 2022-09-06:
Hi Stuart, my current shunt has always a reading of about 4 µV (18 mA) while no charger or load is connected.
Is it possible to calibrate this out or do I have to accept it.

stuartpittaway, 2022-09-06:
Unfortunately this is likely to be noise on the cables, so nothing that can easily be zero'ed out.  It may be possible to do this via a software change in the future.

Do you know if the 18mA is constant across the whole current measurement range?

MatthiasN73, 2022-09-06:
No idea.
I only have a current clamp for such high currents and i think its not very accurate.

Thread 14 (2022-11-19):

"Actual shunt mV reading" not working when current is positive

stuartpittaway, 2022-11-19:
"Actual shunt mV reading" value is incorrectly reported when the battery is charging - looks like a code error with 2 compliement calc.

This doesn't affect the readings from the monitor

Closed 2023-02-20.

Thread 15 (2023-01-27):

Help programming new latest code into the current shunt.

anthonyevs, 2023-01-27:
I have a problem with the current shunt. It came to me pre programmed, and the issue is the shunt wont accept any new setup for my battery, ie, in basic settings its not saving my settings.
Stuart has updated the code and is ready to download via github.
I havent got an UPDI programmer, thinking i should buy one, or convert my arduino UNO into one
I have followed steps to convert the arduino into a jtag2updi interface.
The sketch i loaded was from Eltangas and i have followed the steps to upload this sketch onto the arduino.
Can anyone give a method / instruction to get the arduino to program the current shunt with the latest code....
or,
give advice on which UPDI programmer i should buy, and how expensive are they,
Im assuming the UPDI programming is straight forward, so i`d lean that way for the expense.
Any help greatly appreciated in getting the latest software code uploaded onto the current shunt,
Thank you,
Anthony.

stuartpittaway, 2023-01-27:
Hi.  You no longer need an UPDI programmer or old Arduino to program UPDI style chips.

Take a look at this [UPDI Programming](https://github.com/SpenceKonde/AVR-Guidance/blob/master/UPDI/jtag2updi.md#wiring-the-hardware)

You can use a simple USB to Serial adapter instead.

stuartpittaway, 2023-01-28:
Once you turn the Arduino into an UPDI programmer, you then need to use a program on the computer like pyupdi, or jtag2updi (both are Python programs).

This then talks to the Arduino, and in turn to the ATTINY chip connected to that - you "upload" the DIYBMS code from your computer - it's not put onto the Arduino.

deekoowee, 2023-02-05:
Hi,
I have a similar problem, when trying to save basic settings for the current shunt . Controller start the saving procedure, but returns all back to zero (maybe, because the settings doesn't store into 1614 EEPROM ?). Controller and shunt have latest firmware, tried also the Pylontech firmware (which is my goal) on controller without success. Have tried 19200 8N1 and 9600 8N (changed the dip on shunt). Pylontech firmware give RS485 error on display.

1614 programming Arduino UPDI seems to be ok with Avrdude 7.1. Writing and verifying is ok.
Bootup shows continuous red and green 8sec on and then red blinks 5 times.
After red, the green blinks 6 times.
When green stops blinking red blinks once and then 5sec pause
After 5sec pause, red blinks twice with 2sec pause in between then 5sec pause, this happens 4 times.
In fourth time, the red blink only once and bootup starts at beginning.

Tried to figure out the error codes (two blinks means configuration error), but I'm not sure of red first and last single blink.
Checked the INA, 1614 and ADM solderings and tested the conductions, no problems.
Replaced the ADM chip twice and 1614 once, but no help.

Controller works with PZEM, so controllers in not the issue.

I have tested the serial connection with logic analyzer. It shows, that RX is getting some data from controller. TX from 1614 doesn't send anything and XDIR never change state.

What can I check next ?

stuartpittaway, 2023-02-06:
Hello.

If you are getting a regular "red led" flashing every 2 seconds - that's a good sign, communication between the INA and ATTINY chip is working.

So I would expect there to be an issue on the soldering between the RS485 isolator chip and the ATTINY.

The pins are small, so you need a microscope or magnifying glass to confirm no solder joints/bridges.

stuartpittaway, 2023-02-06:
You should see comms from the controller every 4 seconds to the shunt over RS485, thats how frequently it polls.  The protocol is MODBUS if your scope can decode it.

If the shunt receives a valid command, it will flash the green LED.

Can you check with the scope on the actual RX/TX pins on the ATTINY chip?

Additionally, are you using the **pre-compiled** ATTINY code from GITHUB, and programming with avrdude ?

Have you tried swapping A and B connections on one end of the cable, just to check ?

deekoowee, 2023-02-06:
Analyzer can decode MODBUS. This is the 4ms data from controller;
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
Very strange, that the slave ID = 169

No other green flash for valid command.

Actual RX/TX ... Do you mean RX/TX at pinheader ?
I have used those pinheader pins.

Yes, I have used the pre-compiled code from Github and avrdude. Arduino Nano UPDI USB programmer is made with these instructions; [https://daumemo.com/diy-updi-usb-programmer-which-can-be-made-with-cheap-hardware/]

Swapped A and B, but no help.

stuartpittaway, 2023-02-06:
Did you change the modbus address in the controller after using the pzem? Should be 0x90 for diybms

stuartpittaway, 2023-02-07:
Also, check the baud rate is back at 19200 like the screenshot below

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

deekoowee, 2023-02-07:
Modbus address is 90 and baudrate 19200 8N1

stuartpittaway, 2023-02-07:
Ok, have you tried swapping A+B connections on one end of the cable?  Double check the 120ohm resistors are on both ends of the line (are you using wire resistors, or the on-board SMT parts?)

The ATTINY isn't going to respond until it gets a good MODBUS signal - which should be visible on the TX/RX pins.

deekoowee, 2023-02-07:
Yes, I have tried swapping A+B on one end.
Using on-board resistors. JP4 soldered at controller board.

stuartpittaway, 2023-02-07:
Did you also solder the resistor on the shunt side?

deekoowee, 2023-02-07:
R12 is soldered at shunt and JP1 is bridged as default.

stuartpittaway, 2023-02-07:
Ok, I'm running out of ideas here, obviously until the attiny receives a valid modbus message, it won't reply.

Have you installed the dip switches? These should be all off for standard use.

deekoowee, 2023-02-07:
Dip switches are on board and they are off.

deekoowee, 2023-02-07:
I connect the analyzer directly to controller's ESP-module pins IO21 and IO22.
The data is similar as my earlier data. The controller seems to send data to modbus address 169.
Controller web has configured for address 90.
I'm not good enough with software.
Just thinking, could it be possible, that controller has not fully overwrited the modbus address after PZEM test ?

stuartpittaway, 2023-02-07:
It won't hurt to fully flash the esp32 again (select wipe flash).

If you have a scope, also check the i2c pins on the shunt to see traffic to the ina228

deekoowee, 2023-02-08:
Wiped the flash and reprogrammed Esp32.
Same issues continue. Shunt settings would not be saved at controller settings and modbus shows address 169 at controllers IO21/IO22 and shunt RX/TX pinheader.

I2C have some traffic on SDA ans SCL

stuartpittaway, 2023-02-08:
Can the scope decode the RS485 from A/B connection ?

I can't see anywhere in the code which would force 169 modbus address.  Does the scope support little endian format?

stuartpittaway, 2023-02-08:
Another thought - if you swap back to using the PZEM device, does the scope read the correct modbus address from that? (address should be 1)

deekoowee, 2023-02-08:
Sorry, my fault of using the analyzer. Having the LSB first and got;
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
Now, the address shows 90.
Around 2,8s after RX, TX have one pulse, but no data.

stuartpittaway, 2023-02-08:
Great, does the green led flash on the shunt when that data arrives?

deekoowee, 2023-02-08:
No other green flash, except long green + 6 flashes at boot sequence

stuartpittaway, 2023-02-08:
Ok, just checking it's an attiny1614 chip you installed.

You see the modbus signal on the Rx pin on the shunt?

deekoowee, 2023-02-08:
Yes, it is attiny1614.
Yes, modbus signal is from shunt RX pin

stuartpittaway, 2023-02-08:
Ok, it could be something like the fuses on the attiny.
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
stuartpittaway, 2023-02-21:
Each inverter is quite specific on the wiring.

Try connecting it up without the ground to start with and see if it works - this can help to avoid ground loops.

anthonyevs, 2023-02-21:
Thanks Stuart, Ive connected as stated, blue is Can-H, blue/white is Can-L, set the bms to pylontech protocol and enabled, the inverter has seen it, and i get the CAN ok message on the inverter so it is working.
Now, the bms needs the current shunt to work, as my battery is currently at 83% (measured by a seperate shunt, a junctek VA monitor) I am using this as an extreme out of operating conditions emergency stop control method, to trip the relay / contactors if the bms goes awol or the inverter goes awol, then this will act as an out of condition final emergency stop, probably overkill as a 3rd control measure, but i dont mind.

anthonyevs, 2023-02-21:
Hi Stusrt, please wee the pic of the shunt set up page. It will not save the fully charged value, tail current or efficiency. Also see the adv settings values.
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

anthonyevs, 2023-02-21:
Also, to answer one of your questions, the voltage is reading pretty much the same as the bms, its reading 0.2v higher

deekoowee, 2023-02-21:
The remaining 0,04A charging error is solved also and current reading with disconnected charger is zero now.
I found fix from INA datasheet. I connected the shunt module +V SENSE to shunt resistor load side of shunt resistor and shunt module +++ to battery side of shunt resistor.
I have charged the bank for several days with small current. Diybms charging current reading differs only 0,02A at 1A charging current, comparing to multimeter reading.
Difference was same with 4A charging current.

Should I reset the S.o.C. % after the bank has reached the top voltage ?

anthonyevs, 2023-02-21:
hi stuart, yes, the bms does report success when i hit save.
the controller is on latest code.
The shunt..No.. i have today got thro the post a usbttl adaptor with the 3.3 - 5 v switch, the one that was recommended on one site to use as a updi programmer.
Now, to use it, do i use pyupdi software and this usbttl device to program the shunt?
Ive watched all your videos now, inc the latest one on the v4.5 cell boards that also uses the updi mthod, but i cant see any wlak thro you have done to get the code onto the devices.
Any chance you could compile a very short video on how to do it, it would be soo beneficial for us newbies to programming.
Thanks.

stuartpittaway, 2023-02-22:
@deekoowee sounds great.

@anthonyevs Does this help?  https://github.com/microchip-pic-avr-tools/pymcuprog#serial-port-updi-pyupdi
pyupdi software is usually used with a USB TTL adapter like you have.  On the DIYBMS modules, the top most pin is positive, then data, then ground.  You will need a small resistor (1K) as well to the data line.

I generally follow the guidance from here... https://github.com/SpenceKonde/AVR-Guidance/blob/master/UPDI/jtag2updi.md#wiring-the-hardware

anthonyevs, 2023-02-24:
Hi Stuart, ive loaded python into pyupdi, watched a few videos on youtube, created a flder as a test, and written a test program ("hello world") and played it, all worked ok, pyupdi and pthon has been installed correctly proving all is working as it should. I found this script on openenergy forums, ok, this script is for the arduino method, wheras i`m using the pyupdi.
the script: golderavrdude -v -p attiny1614 -C avrdude.conf -c jtag2updi -b 115200 -P "COM8" -F -U flash:w:diyBMSCurrentMonitor_ATtiny1614.hex:i
I am learning fast tho.
Now that i have proven i can write a basic script, and play it successfully, does a script exist for use with pyupdi to load your code into the current shunt, or do i need to create the script?

anthonyevs, 2023-02-24:
would this be a good script
script ("attiny1614 -b9600 -P"com5" -F -U flash:w:diyBMSCurrentMonitor_ATtiny1614.hex")
or do i need to highlight the path where that file is stored on my pc.
Thanks

anthonyevs, 2023-02-26:
Hi Stuart,
i have now thankfully updated the current shunt using the arduino jtag2updi method. Thank you for your help, this for me was a step I would never have made without your help and without the help of John and Gazza on open energy monitor forum.
Thank you.
Issue resolved.
Anthony.

stuartpittaway, 2023-02-27:
Fantastic - well done.

Closed 2023-02-27.

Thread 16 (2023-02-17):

Current reading not correct

stefanK74, 2023-02-17:
The shunt board (500A/50mV) seems to be electrically working, but current readings are not correct.
The displayed current/power values also do not correlate to the amps going in or out.
The shunt´s voltage reading seems to be ok.

Upon powering up the shunt the green/red leds flash: 5xgreen, 1x red, then periodicaly green and red
Shunt is installed in the positive cable.
Vsense wire is connected to the battery.

Platform & Version
Host name: DIYBMS-009C7938
Processor: ESP32
Version: 7eebc8252a0a6f83da919580a9e9534cacd37f4d
Compiled: 2023-02-14T09:29:32.618Z
Language: en
SDK Version: v4.4.3
Min free Heap: 87912
Free heap: 99280
Heap size: 283788

Any help would be highly appreciated!
Thanks!

At this point in time the batteries were charged with about 47 Amps.
mqtt: {"valid":1,"voltage":54.029,"current":-0.0639,"power":3.5919,"mAhIn":0,"mAhOut":10,"temperature":24,"relayState":0,"soc":89.49}

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

stuartpittaway, 2023-02-17:
Ok, assume the shunt voltage @ 54.02V is correct.

Can you confirm that the shunt is installed in the POSITIVE cable - AFTER all the 4 banks merge together.

You then also have the two sensor wires connected to the shunt (normally screw terminals) directly to the shunt PCB (normally soldered to board).

Additionally, you have two power feeds going directly from the battery (after positive merged together) to both "+++" and "+VSENSE" terminals ?

A very crude diagram...

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

stefanK74, 2023-02-17:
>Can you confirm that the shunt is installed in the POSITIVE cable - AFTER all the 4 banks merge together.
Yes.

>You then also have the two sensor wires connected to the shunt (normally screw terminals) directly to the shunt PCB (normally soldered to board).
Yes, 2 sensor wires soldered to the board.

>Additionally, you have **two power feeds** going directly from the battery (after positive merged together) to both "+++" and "+VSENSE" terminals ?
I have **1 power feed / positive cable** going from the battery to the shunt and bridge "+++" and "+VSense" on the screw terminals on the shunt board.

stuartpittaway, 2023-02-17:
Thanks, given how low the current reading is, there may be a short/solder bridge on the input terminals.

Can you **disconnect** both of the wires to the shunt "kelvin" connections (small screw terminals) and using a multimeter, test the resistance between the two sensor wires?

Additionally, check the resistance between pins 9 and 10 on the INA228 chip, as those pins are only 0.5mm apart, I suspect there's a very small solder bridge between those two pins - or one of them is not soldered to the PCB correctly.

stuartpittaway, 2023-02-17:
Ok - you might be able to just re-heat the existing board to sort out the solder joints.

red0909, 2023-02-18:
i have the 500 amp 50mv shunt too
no issues

stuartpittaway, 2023-04-24:
@stefanK74 did you get this fixed?

stefanK74, 2023-04-24:
Unfortunately not, I resoldered the INA228 and checked pin9+10, but that didn´t help. I need to look into it one more time..

stefanK74, 2023-05-09:
I assume it´s a soldering issue and put his board on the shelf..
Since INA228s are available again I will populate a new board.
Thanks everyone for your feedback!

Closed 2023-05-09.

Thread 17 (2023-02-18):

Shunt resets only to 99%

red0909, 2023-02-18:
the shunt reset to 99% not to 100% looks like a bug.

[Release-2023-01-25-12-26]

stuartpittaway, 2023-02-20:
Do you have "Charge efficiency factor %" set to 99% ?

That will have the effect of subtracting 1% from the 100% on reset.

red0909, 2023-02-20:
yes charge efficency was at 99%

interesting, if the shunt should reset to 100% at full charge it reset to the Charge efficiency factor % value

this was not the case with older firmware

stuartpittaway, 2023-02-23:
The whole SoC calculation is different in this version - the previous one was incorrect.

It doesn't set to the charge efficiency factor % directly.  The SoC is calculated on the amps in vs out, and the factor % is applied to the "in" value to determine the SoC.

red0909, 2023-02-23:
what is the charge efficency factor for, if it has to be set to 100% ?

make no sence for me, ok i will set it to 100%...

stuartpittaway, 2023-02-23:
When you charge any battery, some energy is lost - thats the efficiency.

Lithium cells are very good - hence 99%+ - lead acid less so, probably 90%

red0909, 2023-02-23:
i undestand but in this case if i set 99,5% efficency it wil never reset to 100%... but i have to

stuartpittaway, 2023-02-23:
Ok, set it to 100% then.

deekoowee, 2023-03-27:
I have firmware 40792eb5 and I'm thinking of SoC calculation.
Bank is 14S Lithium and fully charged voltage is set for testing to 58,8V.
Charge efficiency factor is 100%
SoC goes a bit over 100% at 58,8V max, but after a while returns to 100%.

When discharging, voltage drops for example to 53,14V, SoC changes to 72,34%.
With linear voltage drop calc between 58,8 and 50.4, the SoC at 53V is 30%

Maybe there's something, which I don't underestand.
Any ideas ?

stuartpittaway, 2023-03-27:
Voltage has nothing to do with the SoC calculation !

Its only used to identify when 100% fully charged has been reached - 58.8V in your case.

After that, its down to amp-hour counting.

You can't apply a linear voltage drop calc to Lithium cells, they don't have a linear charge curve.

red0909, 2024-02-23:
any news on this issue?

stuartpittaway, 2024-02-24:
The state of charge does indeed reset to 100% when the conditions are met, however from that 100% value the charge efficiency is removed, typically this introduces the 99% value you see.

red0909, 2024-02-25:
hmm, so i have to live with the 99% on full?
if i set the efficency to 100% then the soc calculation is to high if the battery dont charge full for a week

stuartpittaway, 2024-02-25:
There has been a code change submitted by another use to change the behaviour so that the soc goes to 100%, but that's not been incorporated into the main code base.

red0909, 2024-02-25:
could you please integrate it in the external shunt firmware, if its not to much work?
i dont know how to do it.
thanks

stuartpittaway, 2024-02-27:
This is related to issue https://github.com/stuartpittaway/diyBMSv4ESP32/issues/232

red0909, 2025-01-07:
so can you please fix that issue for the external shunt?

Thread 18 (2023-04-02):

Current Shunt relay logic not activating

cass3825, 2023-04-02:
I cannot seem to trigger the relay. See screenshot for configuration which i believe should be triggering at least three limits.
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

stuartpittaway, 2023-04-02:
I'm not sure about using zeros in settings for the relay.

Are you using the latest firmware on the shunt board?

cass3825, 2023-04-02:
Changed zeros to 0.1 and -0.1, same result. Firmware version 40792eb5 dated 25 Jan 2023.

stuartpittaway, 2023-04-03:
Ok, needs to be investigated more thoroughly, but I'm not near a computer for a few days now.

Just for information, what are you running from the shunt relay?

cass3825, 2023-04-03:
Thanks for looking into it! The shunt relay will initiate a generator start, triggered by the under voltage limit.

stuartpittaway, 2023-04-03:
Ok, don't forget the relays on the controller can also do that for you!

cass3825, 2023-04-03:
Controller relays are assigned to Charge Permissive, Discharge Permissive, Non-critical Load Shed & Battery Heater. It seems the more output channels you provide, the more applications we dream up! Lol

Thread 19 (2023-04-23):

Not rally an issue but a request.... couldnt see a request tab!

anthonyevs, 2023-04-23:
Hi Stuart,
I am using the diybms with the original shunt, and its running really well.
I do have a request though.
Is there any chance we can have a tab which could be selected onto our diybms homepage that shows the AH remaining.
I realise e have % capacity remaining, but for me id love to see a AH remaining tab. I dont really use the total ah in and out tabs, but a AH remaining tab for me would be really useful.
If only to see over time the reduction in battery capacity due to losses / wear.
Thanks Stuart.

stuartpittaway, 2023-04-24:
Hi Anthony, at first I thought this was going to be an easy request!

Showing remaining amp-hours based on the fixed capacity provided in the user interface should be straight forward.

You mention you wish to see the capacity due to wear/usage, that sounds quite complicated to calculate.

Any ideas?

anthonyevs, 2023-04-24:
Hi Stuart,
I was thinking, been as the shunt accurately counts in and out the AH into the battery, we could do this.
1. Drain the battery to your personalised setting low cut off point.
2. fill the battery to your personalised settings for the high cut off point.
3. Record the AH taken in by that charge, lets say that is 100AH of energy the battery has taken, so that also equates to 100% SOC. That now represents your starting point going forward, as on this date, your battery at 100% SOC had 100AH capacity.
4. Do the same procedure 1 year in of ownership, and do a drain / charge cycle from your same existing min max personalised settings.. If the battery now only takes 96AH to max charge, this still equates to 100% SOC, but you can see over the 1 yr of ownership and usage, the battery has lost 4 AH of its capacity through wear.
5. That will show what our battery performance has been over a set time period.
6. Also, i personally like the idea of seeing the AH remaining in a tab, for me it would have a meaning i can relate to and understand (although also SOC remaining is very clear too, but SOC doesnt represent the actual AH remaining)

Hope this makes sense Stuart.

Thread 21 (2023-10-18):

CPL files

BorisvdsHA, 2023-10-18:
CPL files do not seem correct for BMS and shunt. JLPCB refuses to go further. Says positions are missing.

BorisvdsHA, 2023-10-18:
ModuleV490-AllInOne and shunt

stuartpittaway, 2023-10-18:
What is the exact message you are receiving?  Can you upload a screenshot?

BorisvdsHA, 2023-10-18:
I downloaded the gerber zip file, Jl BOM and cpl from this folder. The RAW files.

[diyBMS-CurrentShunt](https://github.com/stuartpittaway/diyBMS-CurrentShunt/tree/master)/[CurrentShuntCircuit](https://github.com/stuartpittaway/diyBMS-CurrentShunt/tree/master/CurrentShuntCircuit)
/export/

BorisvdsHA, 2023-10-18:
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

BorisvdsHA, 2023-10-18:
I added the gerber, works perfect. I added BOM and CPL, works perfect. But the next step does not work. Gives this error. I think it is also the case for the BMS 16s.

Nevertheless great work, looking if I can put it together. I have have used easyeda before to test. I have a little experience with esphome an HA. Thanks.

stuartpittaway, 2023-10-19:
That's a new message JLC have introduced recently - you can ignore it, they cannot fit those parts so they are excluded from the BOM

BorisvdsHA, 2023-10-19:
OK thanks.

Closed 2023-10-19.

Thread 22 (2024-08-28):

Feature Request - dynamic capacity and SoC calibration

laserranger3000, 2024-08-28:
Currently, indicated 0% SoC does not always correlate with real 0% SoC due to these reasons:

- fixed battery capacity value in the configuration
- real capacity is changing due to temperature / load / aging etc.
- indicated SoC drift due to shunt inaccuracies and inaccurate charge efficiency setting (I mostly limit the SoC to 80%, I noticed a significant drift if I'm not charging to 100% at least once a month)

My proposal would be to calibrate the indicated SoC to 0% as soon as the lowest cell falls below a configurable value (e.g. 3V) for some time.
Also, the calculated Ah between calibrated 100% and 0% in a full cycle can be automatically set as new capacity for future SoC estimations.
Future improvements could also be factors that consider the cell temperature and load in the SoC calculation. (e.g. 5% capacity loss for each 10K below 20°C, configurable. Similar factors for the C-rate could be used aswell)

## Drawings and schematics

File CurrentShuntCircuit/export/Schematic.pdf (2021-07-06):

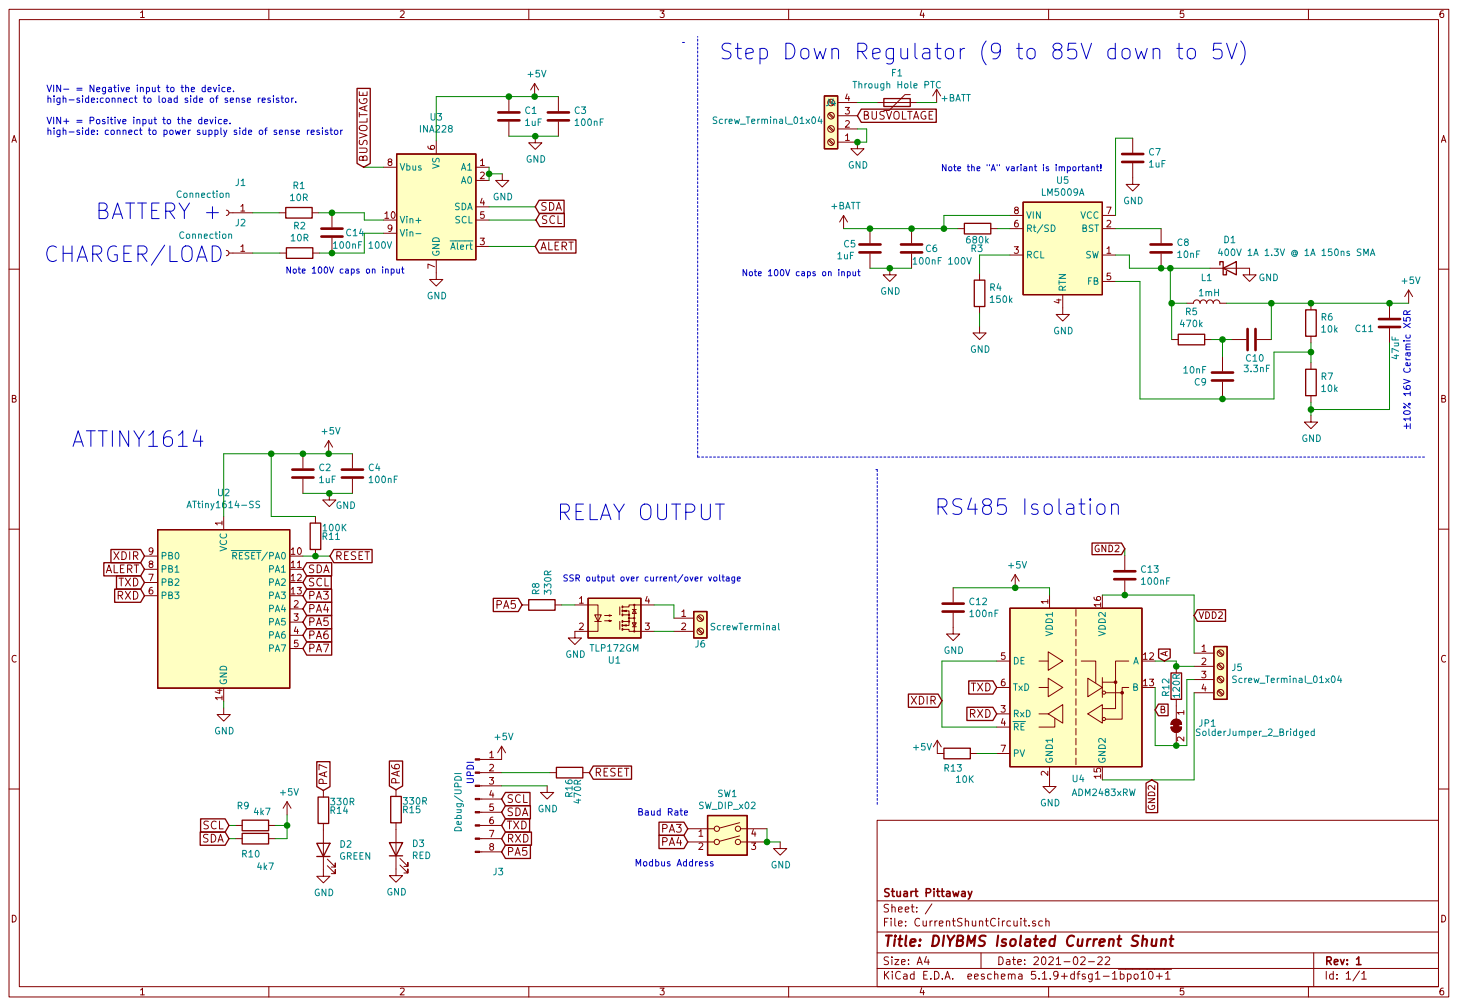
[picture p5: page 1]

Step Down Regulator (9 to 85V down to 5V)

VIN- = Negative input to the device.
high-side:connect to load side of sense resistor.

VIN+ = Positive input to the device.

Note the "A" variant is important!

4 FB 5 Rt/SD 6 VCC 7 VIN 8 U5

Note 100V caps on input BATTERY +
CHARGER/LOAD

1 RESET/PA0 10 PA1 11 PA2 12 PA3 13 GND 14 PA4 2 PA5 3 PA6 4 PA7 5 PB3 6 PB2 7 PB1 8 PB0 9 U2 ATtiny1614-SS GND

SSR output over current/over voltage

2 RxD 3 RE 4 DE 5 TxD 6 PV 7 U4ADM2483xRW

Id: 1/1 Title: DIYBMS Isolated Current Shunt File: CurrentShuntCircuit.sch Sheet: / Stuart Pittaway

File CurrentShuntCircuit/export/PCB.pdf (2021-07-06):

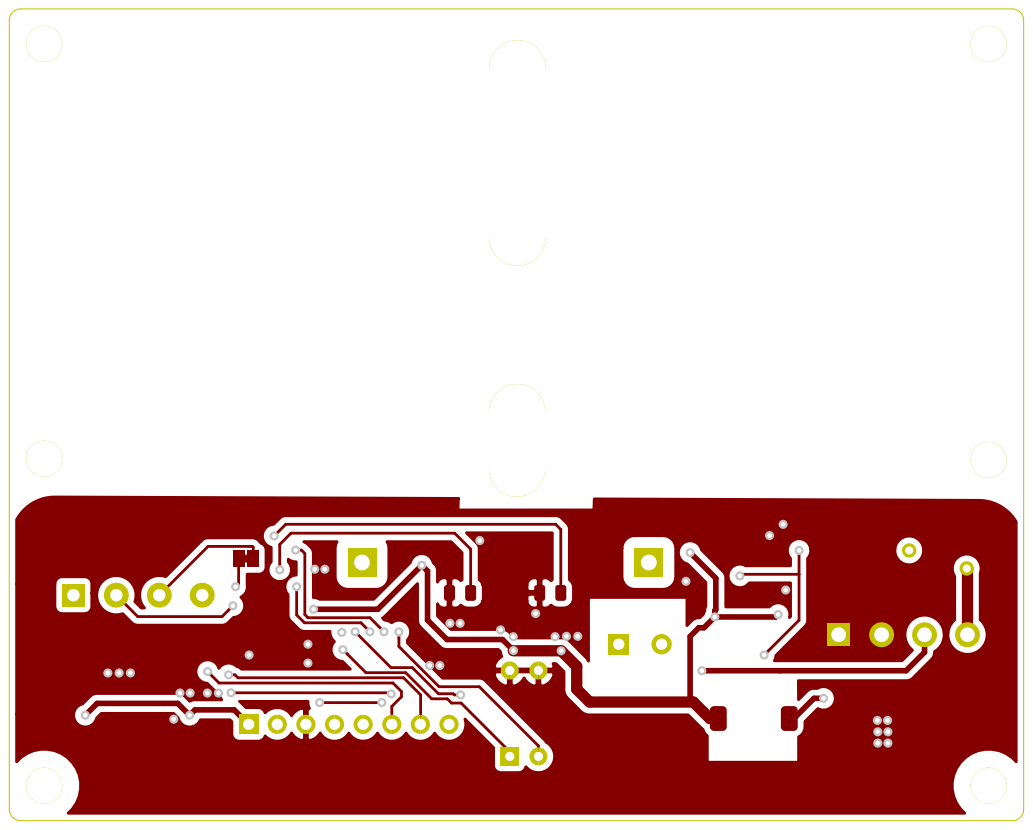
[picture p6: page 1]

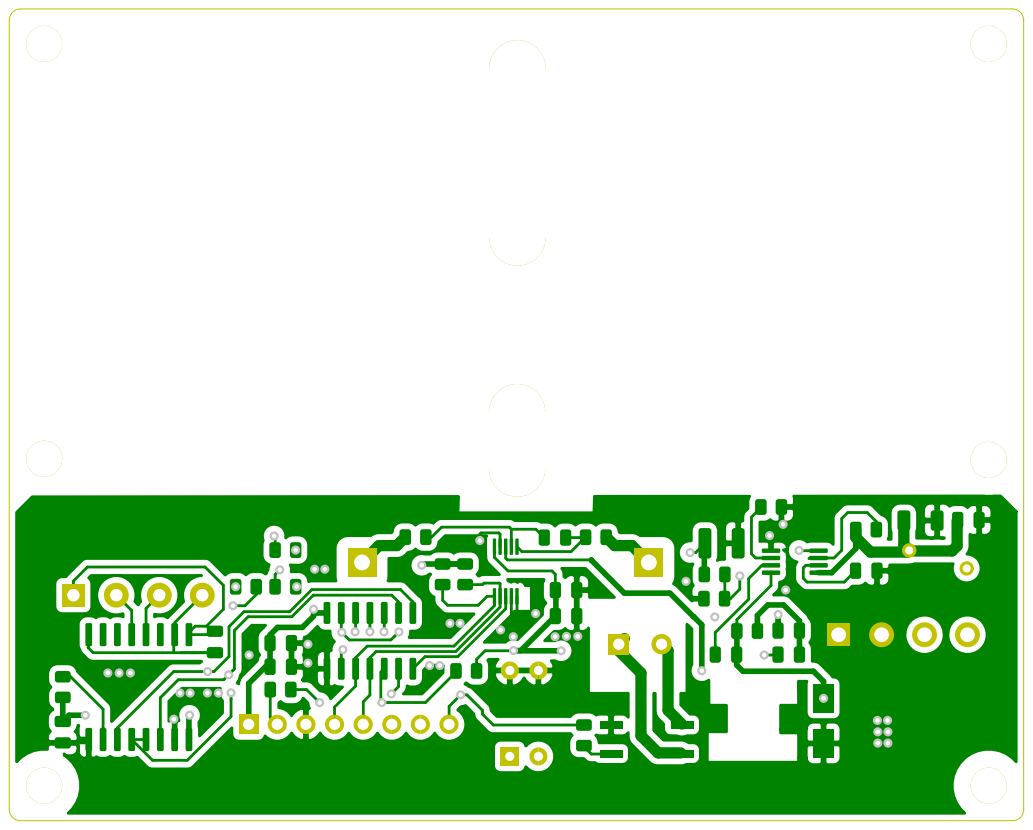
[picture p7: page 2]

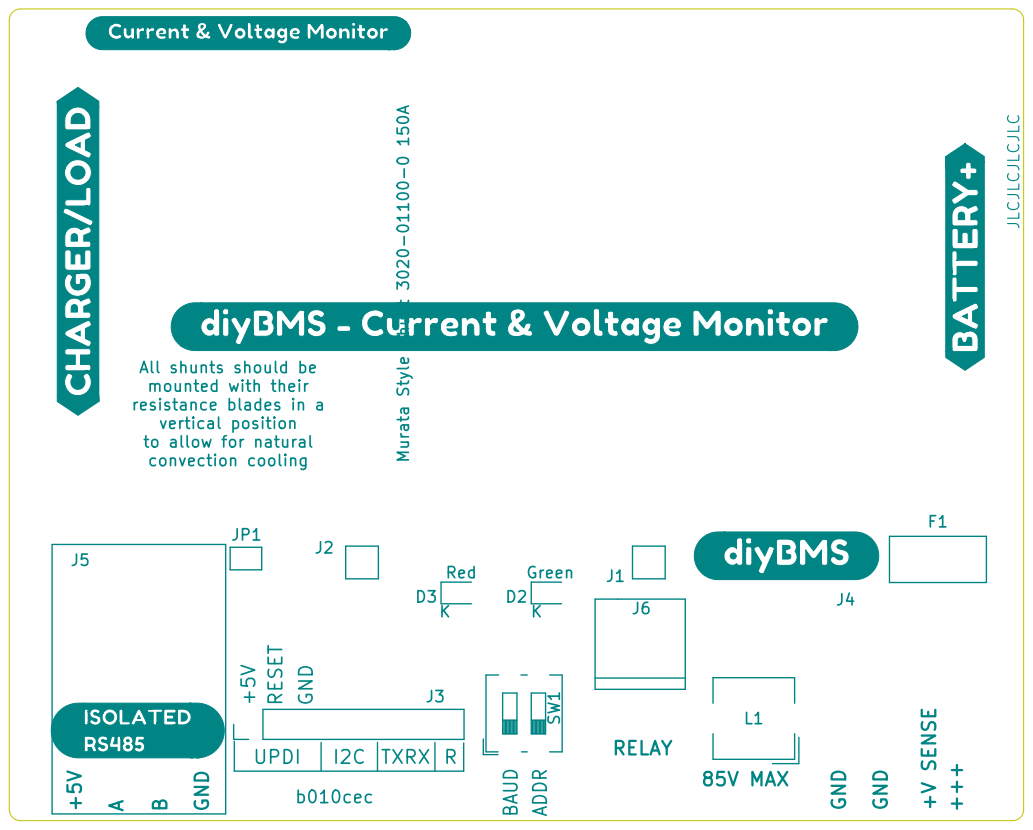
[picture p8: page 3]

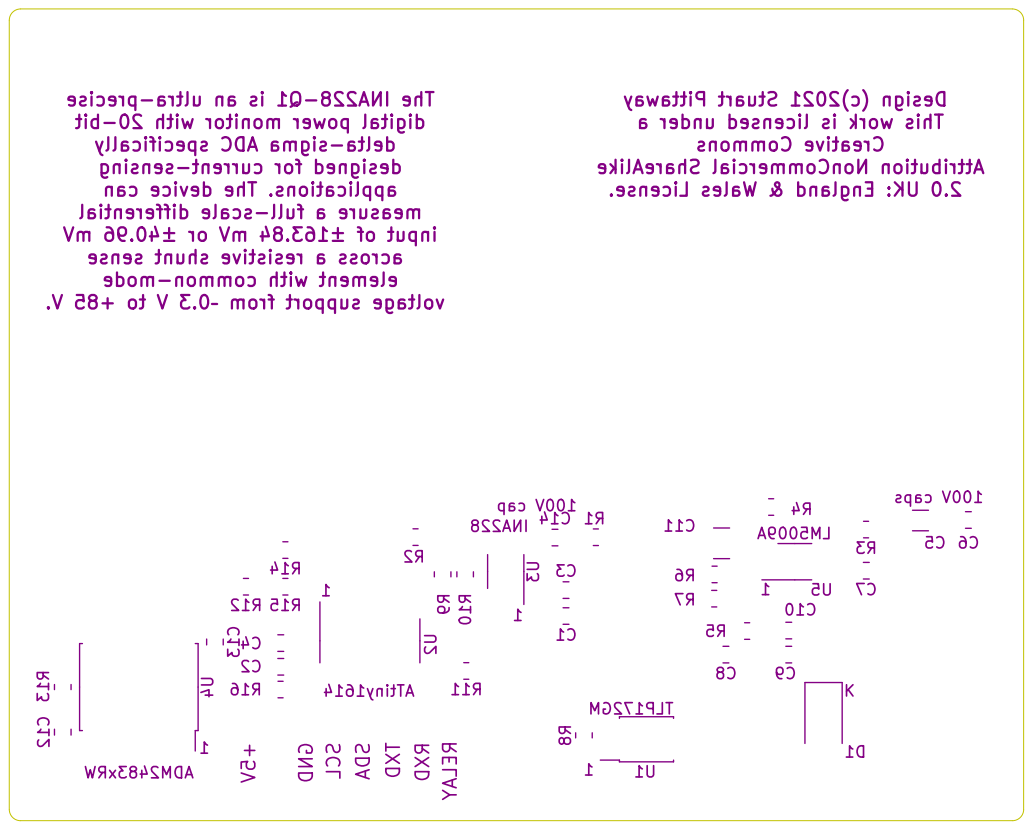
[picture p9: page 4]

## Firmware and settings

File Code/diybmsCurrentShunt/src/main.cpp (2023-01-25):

/*
 ____  ____  _  _  ____  __  __  ___    _  _  __
(  _ \(_  _)( \/ )(  _ \(  \/  )/ __)  ( \/ )/. |
 )(_) )_)(_  \  /  ) _ < )    ( \__ \   \  /(_  _)
(____/(____) (__) (____/(_/\/\_)(___/    \/   (_)

DIYBMS V4.0
CURRENT & VOLTAGE MONITORING SYSTEM BASEDO ON TEXAS INST. INA228

(c)2021 Stuart Pittaway

COMPILE THIS CODE USING PLATFORM.IO

LICENSE
Attribution-NonCommercial-ShareAlike 2.0 UK: England & Wales (CC BY-NC-SA 2.0 UK)
https://creativecommons.org/licenses/by-nc-sa/2.0/uk/

* Non-Commercial — You may not use the material for commercial purposes.
* Attribution — You must give appropriate credit, provide a link to the license, and indicate if changes were made.
  You may do so in any reasonable manner, but not in any way that suggests the licensor endorses you or your use.
* ShareAlike — If you remix, transform, or build upon the material, you must distribute your
  contributions under the same license as the original.
* No additional restrictions — You may not apply legal terms or technological measures
  that legally restrict others from doing anything the license permits.

** COMMERCIAL USE AND RESALE PROHIBITED **

*/

// ATTINY1614 (tinyAVR® 1-series of microcontrollers)
// http://ww1.microchip.com/downloads/en/DeviceDoc/ATtiny1614-data-sheet-40001995A.pdf

// MODBUS Protocol
// https://www.ni.com/en-gb/innovations/white-papers/14/the-modbus-protocol-in-depth.html

// INA228 85-V, 20-Bit, Ultra-Precise Power/Energy/Charge Monitor
// https://www.ti.com/lit/ds/symlink/ina228.pdf

#if !defined(MODBUSDEFAULTBAUDRATE)
#error MODBUSDEFAULTBAUDRATE must be defined
#endif
#if !defined(MODBUSBASEADDRESS)
#error MODBUSBASEADDRESS must be defined
#endif
#if !defined(MODBUSSERIALCONFIG)
#error MODBUSSERIALCONFIG must be defined
#endif

#include <Arduino.h>
#include <avr/sleep.h>
#include <avr/power.h>
#include <avr/wdt.h>
#include <Wire.h>
#include <EEPROM.h>

#include <FastCRC.h>

FastCRC16 CRC16;

#include "main.h"
#include "settings.h"

#include "EmbeddedFiles_Defines.h"

#include "SimpleModbusSlave.h"

#define GREENLED_PIN_BITMAP PIN7_bm
#define REDLED_PIN_BITMAP PIN6_bm
#define RELAY_PIN_BITMAP PIN5_bm

// Sequences used to indicate error on RED led
// Single flash
const static uint32_t err_INA228Missing = 0xF000000F;
// Two flashes
const static uint32_t err_InitialConfigure = 0xF0F0000F;
// 3 flashes
const static uint32_t err_WrongChip = 0xF0F0F00F;
// 4 flashes (0xCC=2 flashes)
const static uint32_t err_WriteConfig = 0xCCCC000F;
// 5 flashes (0xC0=1 short flash)
const static uint32_t err_WriteADCConfig = 0xCCCCC00F;
// 6 flashes
const static uint32_t err_WriteRegisters = 0xCCCCCC0F;
// 7 flashes (0xAA=4 fast flashes)
const static uint32_t err_INA228Reset = 0xAAA8000F;
// 8 flashes  10101010101010100000000000001111
const static uint32_t err_CheckSumErr = 0xAAAA000F;
// 9 flashes 00101010101010101010000000001111
const static uint32_t err_ResetChargeEnergyRegisters = 0x2AAAA00F;

typedef union
{
  double dblvalue;
  uint16_t word[2];
} DoubleUnionType;

const double full_scale_adc = 40.96;
// const double CoulombsToAmpHours = 1.0 / 3600.0;
const double CoulombsToMilliAmpHours = 1.0 / 3.6;
const uint8_t INA228_I2C_Address = B1000000;

const uint16_t loop_delay_ms = 2000;

uint32_t milliamphour_out_lifetime = 0;
uint32_t milliamphour_in_lifetime = 0;

uint32_t daily_milliamphour_out = 0;
uint32_t daily_milliamphour_in = 0;

uint32_t milliamphour_out = 0;
uint32_t milliamphour_in = 0;

uint32_t milliamphour_out_offset = 0;
uint32_t milliamphour_in_offset = 0;

uint16_t ModBusBaudRate = MODBUSDEFAULTBAUDRATE;

uint8_t ModbusSlaveAddress = MODBUSBASEADDRESS;

volatile bool relay_state = false;
volatile bool config_dirty = false;

uint8_t max_soc_reset_counter = 0;
uint8_t soc_reset_counter = 0;
int32_t last_charge_coulombs = 0;

unsigned long timer = 0;

#define combineBytes(high, low) (high << 8) + low

// This structure is held in EEPROM, it has the same register/values
// as the INA228 chip and is used to set the INA228 chip to the correct parameters on power up

// On initial power up (or EEPROM clear) these parameters are read from the INA228 chip
// to provide defaults.  Some values are overridden in code (like ADC_CONFIG and CONFIG)
// to configure to our prescribed needs.
struct eeprom_regs
{
  uint16_t R_CONFIG;
  uint16_t R_ADC_CONFIG;
  uint16_t R_SHUNT_CAL;    // Shunt Calibration
  uint16_t R_SHUNT_TEMPCO; // Shunt Temperature Coefficient
  uint16_t R_DIAG_ALRT;
  uint16_t R_SOVL;
  uint16_t R_SUVL;
  uint16_t R_BOVL;
  uint16_t R_BUVL;
  uint16_t R_TEMP_LIMIT;
  uint16_t R_PWR_LIMIT;

  // Holds what alert events trigger the relay to turn on/high
  // uses the same values/mapping as enum DIAG_ALRT_FIELD
  uint16_t relay_trigger_bitmap;

  uint16_t shunt_max_current;
  uint16_t shunt_millivolt;

  // LSB step size for the CURRENT register where the current in Amperes is stored
  double CURRENT_LSB;
  // Resistance of SHUNT in OHMS
  double RSHUNT;

  uint16_t batterycapacity_amphour;
  double fully_charged_voltage;
  double tail_current_amps;
  double charge_efficiency_factor;
};

eeprom_regs registers;

volatile bool ALERT_TRIGGERED = false;
uint16_t alert = 0;

volatile bool wdt_triggered = false;
volatile uint16_t wdt_triggered_count;

uint16_t CalculateSOC()
{
  double milliamphour_in_scaled = ((double)milliamphour_in / 100.0) * registers.charge_efficiency_factor;
  double milliamphour_batterycapacity = 1000.0 * (uint32_t)registers.batterycapacity_amphour;
  double difference = milliamphour_in_scaled - milliamphour_out;

  double answer = 100 * (difference / milliamphour_batterycapacity);
  if (answer < 0)
  {
    // We have taken more out of the battery than put in, so must be zero SoC (or more likely out of calibration)
    return 0;
  }

  // Store result as fixed point decimal
  uint16_t SOC = 100 * answer;

  // Add a hard upper limit 999.99%
  if (SOC > 99999)
  {
    SOC = 99999;
  }

  return SOC;
}

void ConfigurePorts()
{
  // PA1 = SDA
  // PA2 = SCL
  // PA3 = Baud Rate
  // PA4 = Modbus Address
  // PA5 = RELAY OUTPUT
  // PA6 = RED LED
  // PA7 = GREEN LED

  // Set pins as Outputs (other pins are inputs)
  PORTA.DIR = GREENLED_PIN_BITMAP | REDLED_PIN_BITMAP | RELAY_PIN_BITMAP;

  // Relay off by default
  PORTA.OUTCLR = RELAY_PIN_BITMAP;

  // Set Port B digital outputs
  // PB0 = XDIR (RS485 transmit enable)
  // PB1 = ALERT
  // PB2 = TX (has to be set as output on tiny1614)
  // PB3 = RX
  // Set pins as Outputs (other pins are inputs)
  PORTB.DIR = PIN0_bm | PIN2_bm;
  PORTB.PIN1CTRL = PORT_PULLUPEN_bm | PORT_ISC_enum::PORT_ISC_BOTHEDGES_gc;

  PORTB.OUTSET = PIN2_bm; // TX is high

  USART0.CTRLB = USART_RXEN_bm | USART_TXEN_bm; // enable rx and tx
  // Enable interrupts
  sei();
}

// Read the jumper pins
void ReadJumperPins()
{
  // Switch pull ups on for the pins, if they are jumpered they are pulled to ground
  PORTA.PIN3CTRL = PORT_PULLUPEN_bm;
  PORTA.PIN4CTRL = PORT_PULLUPEN_bm;

  // PA3 = Baud Rate
  // PA4 = Modbus Address

  // High value means unconnected/not jumpered
  bool BaudRateJumper = (PORTA.IN & PIN3_bm);
  bool AddressJumper = (PORTA.IN & PIN4_bm);

  // TODO: Do something with the above jumper settings
  if (BaudRateJumper == false)
  {
    // Half the default baud rate if the jumper is connected, so 19200 goes to 9600
    ModBusBaudRate = ModBusBaudRate / 2;
  }

  if (AddressJumper == false)
  {
    // Jumper connected, increase address by 8
    ModbusSlaveAddress += 8;
  }

  // Switch off pull ups
  PORTA.PIN3CTRL = 0;
  PORTA.PIN4CTRL = 0;
}

void RedLED(bool value)
{
  if (value)
  {
    PORTA.OUTSET = REDLED_PIN_BITMAP;
  }
  else
  {
    PORTA.OUTCLR = REDLED_PIN_BITMAP;
  }
}

void GreenLED(bool value)
{
  if (value)
  {
    PORTA.OUTSET = GREENLED_PIN_BITMAP;
  }
  else
  {
    PORTA.OUTCLR = GREENLED_PIN_BITMAP;
  }
}

void EnableWatchdog()
{
  wdt_triggered = false;

  // Enter protection mode
  CCP = 0xD8;

  // 8 seconds
  WDT.CTRLA = WDT_PERIOD_enum::WDT_PERIOD_8KCLK_gc;

  wdt_reset();
}

/*
void DisableSerial0TX()
{
  //On tiny1614 this saves about 10mA of current
  USART0.CTRLB &= ~(USART_TXEN_bm); // Transmitter Enable bit mask.
}

void EnableSerial0TX()
{
  //When the transmitter is disabled, it will no longer override the TXD pin, and the pin
  //direction is automatically set as input by hardware, even if it was configured as output by the user
  //PB2 as OUTPUT
  PORTB.DIRSET = PIN2_bm;
  USART0.CTRLB |= USART_TXEN_bm; // Transmitter Enable bit mask.
}
*/

void WatchdogTriggered()
{
  // This is the watchdog timer - something went wrong and no serial activity received in over 8 seconds
  wdt_triggered = true;
  wdt_triggered_count++;
}

bool i2c_writeword(const uint8_t inareg, const uint16_t data)
{
  Wire.beginTransmission(INA228_I2C_Address);
  Wire.write(inareg);
  Wire.write((uint8_t)(data >> 8)); // Write the first (MSB) byte
  Wire.write((uint8_t)data);        // and then the second byte
  uint8_t result = Wire.endTransmission();

  // Delay after making a write to INA chip
  delayMicroseconds(10);

  return result == 0;
}

int16_t i2c_readword(const uint8_t inareg)
{
  Wire.beginTransmission(INA228_I2C_Address);
  Wire.write(inareg);
  uint8_t result = Wire.endTransmission();
  delayMicroseconds(10);
  Wire.requestFrom(INA228_I2C_Address, (uint8_t)2); // Request 2 bytes

  while (!Wire.available())
  {
  };

  uint8_t a, b;
  a = Wire.read();
  b = Wire.read();

  return ((uint16_t)a << 8) | b;
}

uint32_t i2c_readUint24(const uint8_t inareg)
{
  Wire.beginTransmission(INA228_I2C_Address);
  Wire.write(inareg);
  uint8_t result = Wire.endTransmission();
  delayMicroseconds(10);
  Wire.requestFrom(INA228_I2C_Address, (uint8_t)3); // Request 3 bytes
  while (!Wire.available())
  {
  };
  uint8_t a, b, c;
  a = Wire.read();
  b = Wire.read();
  c = Wire.read();

  uint32_t reply = ((uint32_t)a << 16) | ((uint32_t)b << 8) | ((uint32_t)c);

  return reply;
}

uint64_t i2c_readUint40(const uint8_t inareg)
{
  Wire.beginTransmission(INA228_I2C_Address);
  Wire.write(inareg);
  uint8_t result = Wire.endTransmission();
  delayMicroseconds(10);
  Wire.requestFrom(INA228_I2C_Address, (uint8_t)5); // Request 5 bytes
  while (!Wire.available())
  {
  };
  uint8_t a, b, c, d, e;
  a = Wire.read();
  b = Wire.read();
  c = Wire.read();
  d = Wire.read();
  e = Wire.read();

  uint64_t reply = (uint64_t)a << 32;
  reply += (uint64_t)b << 24;
  reply += (uint64_t)c << 16;
  reply += (uint64_t)d << 8;
  reply += (uint64_t)e;

  return reply;
}

int64_t i2c_readInt40(const uint8_t inareg)
{
  Wire.beginTransmission(INA228_I2C_Address);
  Wire.write(inareg);
  uint8_t result = Wire.endTransmission();
  delayMicroseconds(10);
  Wire.requestFrom(INA228_I2C_Address, (uint8_t)5); // Request 5 bytes

  uint8_t a, b, c, d, e;
  a = Wire.read();
  b = Wire.read();
  c = Wire.read();
  d = Wire.read();
  e = Wire.read();

  // Check if a twos compliment negative number
  uint64_t reply = (a & 0x80) ? (uint64_t)0xFFFFFF0000000000 : 0;

  reply += (uint64_t)a << 32;
  reply += (uint64_t)b << 24;
  reply += (uint64_t)c << 16;
  reply += (uint64_t)d << 8;
  reply += (uint64_t)e;

  // Cast to signed integer (which also sorts out the negative sign if applicable)
  return (int64_t)reply;
}

// Read a 24 bit (3 byte) unsigned integer into a uint32 (including right shift 4 bits)
uint32_t readUInt24(const uint8_t inareg)
{
  return i2c_readUint24(inareg) >> 4;
}

// Read a 20 bit (3 byte) TWOS COMPLIMENT integer
int32_t readInt20(const uint8_t inareg)
{
  // Returns
  uint32_t value = readUInt24(inareg);

  // The number is two's complement, check for negative at bit 20
  if (value & 0x80000)
  {
    // Invert
    value = ~value;
    // Trim to 20 bits
    value = value & 0x000FFFFFU;
    // Add 1
    value = value + 1;
    // Return NEGATIVE of the value
    return -(int32_t)value;
  }

  return (int32_t)value;
}

// pattern is a 32bit pattern to "play" on the RED LED to indicate failure
void __attribute__((noreturn)) blinkPattern(uint32_t pattern)
{

  // Show the error 4 times
  for (size_t x = 0; x < 4; x++)
  {
    uint32_t p = pattern;

    // Loop through the 32 bits - takes 1024ms in total
    for (size_t i = 0; i < 32; i++)
    {
      wdt_reset();
      if (p & 1)
      {
        RedLED(true);
      }
      else
      {
        RedLED(false);
      }
      p >>= 1;

      // Give user enough time to count the pulses
      delay(200);
    }

    // Switch off LED and wait half second before repeating
    RedLED(false);
    for (size_t i = 0; i < 40; i++)
    {
      wdt_reset();
      delay(50);
    }
  }

  // Both LEDs on whilst we wait for WDT
  RedLED(true);
  GreenLED(true);

  // Finally just hang - this will trigger the watchdog causing a reboot
  delay(10000);
}

void ResetChargeEnergyRegisters()
{
  // BIT 14
  // RSTACC
  // Resets the contents of accumulation registers ENERGY and CHARGE to 0
  // 0h = Normal Operation
  // 1h = Clears registers to default values for ENERGY and CHARGE registers

  if (!i2c_writeword(INA_REGISTER::CONFIG, registers.R_CONFIG | (uint16_t)_BV(14)))
  {
    blinkPattern(err_ResetChargeEnergyRegisters);
  }
}

volatile uint16_t diag_alrt_value = 0;

void SetINA228ConfigurationRegisters()
{
  if (!i2c_writeword(INA_REGISTER::CONFIG, registers.R_CONFIG))
  {
    blinkPattern(err_WriteConfig);
  }

  if (!i2c_writeword(INA_REGISTER::ADC_CONFIG, registers.R_ADC_CONFIG))
  {
    blinkPattern(err_WriteADCConfig);
  }
}

// Sets SOC by setting "fake" in/out amphour counts
// value=8212 = 82.12%
void SetSOC(uint16_t value)
{
  // Assume battery is fully charged
  milliamphour_in = 1000 * (uint32_t)registers.batterycapacity_amphour;
  // And we have consumed this much...
  milliamphour_out = (1.0 - ((float)value / 10000.0)) * milliamphour_in;

  // Zero out readings using the offsets
  milliamphour_out_offset = milliamphour_out;
  milliamphour_in_offset = milliamphour_in;
}

void SetINA228Registers()
{

#define I2C_WRITE_REG(reg, val)       \
  if (!i2c_writeword(reg, val))       \
  {                                   \
    blinkPattern(err_WriteRegisters); \
  }

  I2C_WRITE_REG(INA_REGISTER::SHUNT_CAL, registers.R_SHUNT_CAL)
  I2C_WRITE_REG(INA_REGISTER::SHUNT_TEMPCO, registers.R_SHUNT_TEMPCO)
  I2C_WRITE_REG(INA_REGISTER::SOVL, registers.R_SOVL)
  I2C_WRITE_REG(INA_REGISTER::SUVL, registers.R_SUVL)
  I2C_WRITE_REG(INA_REGISTER::BOVL, registers.R_BOVL)
  I2C_WRITE_REG(INA_REGISTER::BUVL, registers.R_BUVL)
  I2C_WRITE_REG(INA_REGISTER::TEMP_LIMIT, registers.R_TEMP_LIMIT)
  I2C_WRITE_REG(INA_REGISTER::PWR_LIMIT, registers.R_PWR_LIMIT)
}

void SaveConfig()
{
  WriteConfigToEEPROM((uint8_t *)&registers, sizeof(eeprom_regs));
}

bool SetRegister(uint16_t address, uint16_t value)
{
  static DoubleUnionType newvalue;

  switch (address)
  {
  case 4:
  case 6:
  //|40022|Fully charged voltage (4 byte double)
  case 21:
  //|40024|Tail current (Amps) (4 byte double)
  case 23:
  // Temperature limit (signed int16)
  case 29:
  // Bus Overvoltage (overvoltage protection)
  case 31:
  // BusUnderVolt
  case 33:
  // Shunt Over Voltage Limit (current limit)
  case 35:
  case 37:
  {
    // Set word[0] in preperation for the next register to be written
    newvalue.word[0] = value;
    break;
  }
    /*
  case 5:
  {
    //amphour_out
    newvalue.word[1] = value;
    uint32_t x = newvalue.word[0] << 16 | value;
    charge_c_out = x * CoulombsToMilliAmpHours;
    break;
  }

  case 7:
  {
    //amphour_in
    newvalue.word[1] = value;
    uint32_t x = newvalue.word[0] << 16 | value;
    charge_c_in = x * CoulombsToMilliAmpHours;
    break;
  }
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
void loop()
{
  wdt_reset();

  /*
  //Enable interrupts
  sei();
  //Start frame detection
  USART0.CTRLB |= USART_SFDEN_bm;

  //Switch off TX, saves current
  //DisableSerial0TX();

  if (!Serial.available())
  {
    //Enter sleep
    set_sleep_mode(SLEEP_MODE_STANDBY);
    sleep_enable();
    sleep_cpu();

    //Snoring can be heard at this point....
    sleep_disable();
  }
*/

  if (ALERT_TRIGGERED)
  {
    ALERT_TRIGGERED = false;
    diag_alrt_value = i2c_readword(INA_REGISTER::DIAG_ALRT);

    alert = diag_alrt_value & ALL_ALERT_BITS;

    if (alert == 0)
    {
      RedLED(false);
    }

    // Apply relay_trigger_bitmap bitmask over the top of the alerts, so we only trigger on specific events
    relay_state = ((alert & registers.relay_trigger_bitmap) != 0);

    // Turn relay on/off
    if (relay_state)
    {
      PORTA.OUTSET = RELAY_PIN_BITMAP;
    }
    else
    {
      PORTA.OUTCLR = RELAY_PIN_BITMAP;
    }
  }

  modbus_update();

  if (millis() > timer)
  {

    if (config_dirty)
    {
      SaveConfig();
      config_dirty = false;
    }

    RedLED(true);

    // Do it again in X seconds
    timer = millis() + loop_delay_ms;

    double voltage = BusVoltage();
    double current = Current();

    // We amp-hour count using units of 18 coulombs = 5mAh, to avoid rounding issues

    // If we don't have a voltage reading, ignore the coulombs - also means
    // Ah counting won't work without voltage reading on the INA228 chip
    if (voltage > 0)
    {
      int32_t charge_coulombs = ChargeInCoulombsAsInt();
      int32_t difference = charge_coulombs - last_charge_coulombs;

      // Have we used up more than 5mAh of energy?
      // if not, ignore for now and await next cycle
      if (abs(difference) >= 18)
      {
        if (difference > 0)
        {
          // Amp hour out
          // Integer divide (18 coulombs)
          int32_t integer_divide = (difference / 18);
          // Subtract remainder
          last_charge_coulombs = charge_coulombs - (difference - (integer_divide * 18));
          // Chunks of 5mAh
          uint32_t a = integer_divide * 5;
          milliamphour_out += a;
          milliamphour_out_lifetime += a;
          daily_milliamphour_out += a;
        }
        else
        {
          // Make it positive, for counting amp hour in
          difference = abs(difference);
          int32_t integer_divide = (difference / 18);
          // Add on remainder
          last_charge_coulombs = charge_coulombs + (difference - (integer_divide * 18));
          // chunks of 5mAh
          uint32_t a = integer_divide * 5;
          milliamphour_in += a;
          milliamphour_in_lifetime += a;
          daily_milliamphour_in += a;
        }
      }
    }

    // Periodically we need to reset the energy register to prevent it overflowing
    // if we do this too frequently we get incorrect readings over the long term
    // 360000 = 100Amp Hour
    if (abs(last_charge_coulombs) > (int32_t)360000)
    {
      ResetChargeEnergyRegisters();
      last_charge_coulombs = 0;
    }

    // Now to test if we need to reset SOC to 100% ?
    // Check if voltage is over the fully_charged_voltage and current UNDER tail_current_amps
    if (voltage > registers.fully_charged_voltage && current > 0 && current < registers.tail_current_amps)
    {
      // Battery has reached fully charged so wait for time counter
      soc_reset_counter++;

      // Test if counter has reached 3 minutes, indicating fully charge battery
      if (soc_reset_counter >= ((3 * 60) / (loop_delay_ms / 1000)))
      {
        // Now we reset the SOC, by clearing the registers, at this point SOC returns to 100%

        // This does have an annoying "feature" of clearing down todays Ah counts :-(
        // TODO: FIX THIS - probably need a set of shadow variables to hold the internal SOC and AH counts
        //                  but then when/how do we reset the Ah counts?

        max_soc_reset_counter = soc_reset_counter;
        ResetChargeEnergyRegisters();
        last_charge_coulombs = 0;
        soc_reset_counter = 0;
        SetSOC(10000);
      }
    }
    else
    {
      // Voltage or current is out side of monitoring limits, so reset timer count
      soc_reset_counter = 0;
    }

    if (alert == 0)
    {
      // Turn LED off if alert is not active
      RedLED(false);
    } // end if

  } // end if
}

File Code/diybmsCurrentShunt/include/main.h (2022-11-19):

#include <Arduino.h>


enum INA_REGISTER : uint8_t
{
  CONFIG = 0,
  ADC_CONFIG = 1,
  SHUNT_CAL = 2,    //Shunt Calibration
  SHUNT_TEMPCO = 3, //Shunt Temperature Coefficient
  VSHUNT = 4,       //Shunt Voltage Measurement 24bit
  VBUS = 5,         //Bus Voltage Measurement 24bit
  DIETEMP = 6,
  CURRENT = 7,   //Current Result 24bit
  POWER = 8,     //Power Result 24bit
  ENERGY = 9,    //Energy Result 40bit
  CHARGE = 0x0A, //Charge Result 40bit
  DIAG_ALRT = 0x0b,
  SOVL = 0x0c, //Shunt Overvoltage Threshold
  SUVL = 0x0d, //Shunt Undervoltage Threshold
  BOVL = 0x0e, //Bus Overvoltage Threshold
  BUVL = 0x0f, //Bus Undervoltage Threshold
  TEMP_LIMIT = 0x10,
  PWR_LIMIT = 0x11,
  MANUFACTURER_ID = 0xFE,
  DIE_ID = 0xFF
};

enum DIAG_ALRT_FIELD : uint16_t
{
  ALATCH = 15,
  CNVR = 14,
  SLOWALERT = 13,
  APOL = 12,
  ENERGYOF = 11,
  CHARGEOF = 10,
  MATHOF = 9,
  RESERVED = 8,
  TMPOL = 7,
  SHNTOL = 6,
  SHNTUL = 5,
  BUSOL = 4,
  BUSUL = 3,
  POL = 2,
  CNVRF = 1,
  MEMSTAT = 0
};


const uint16_t ALL_ALERT_BITS = (bit(DIAG_ALRT_FIELD::TMPOL) |
                                 bit(DIAG_ALRT_FIELD::SHNTOL) |
                                 bit(DIAG_ALRT_FIELD::SHNTUL) |
                                 bit(DIAG_ALRT_FIELD::BUSOL) |
                                 bit(DIAG_ALRT_FIELD::BUSUL) |
                                 bit(DIAG_ALRT_FIELD::POL));

void RedLED(bool value);
void GreenLED(bool value);
void CalculateLSB();
double BusVoltage();

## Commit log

2020-08-10 Initial check in
    [cpl_rotations_db.csv, diyBMS-CurrentShunt-B_Cu.gbr, diyBMS-CurrentShunt-B_Mask.gbr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]
2020-08-10 Move files
    [cpl_rotations_db.csv, diyBMS-CurrentShunt-B_Cu.gbr, diyBMS-CurrentShunt-B_Mask.gbr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]
2020-08-11 Change to 0805 parts
    [diyBMS-CurrentShunt.kicad_pcb, diyBMS-CurrentShunt.sch]
2020-08-11 Changed parts to 0805
    [diyBMS-CurrentShunt.kicad_pcb]
2020-08-11 Move 0805 changes
    [diyBMS-CurrentShunt.kicad_pcb, diyBMS-CurrentShunt.sch]
2020-08-11 Layout complete
    [diyBMS-CurrentShunt.kicad_pcb, diyBMS-CurrentShunt.sch]
2020-08-13 More changes
    [diyBMS-CurrentShunt.kicad_pcb, diyBMS-CurrentShunt.sch]
2020-08-17 Added additional parts from data sheet
    [diyBMS-CurrentShunt.kicad_pcb, diyBMS-CurrentShunt.sch]
2020-10-03 Change inductor size
    [diyBMS-CurrentShunt.kicad_pcb, diyBMS-CurrentShunt.sch]
2020-10-03 Updated circuit diagram
    [diyBMS-CurrentShunt.kicad_pcb, diyBMS-CurrentShunt.sch]
2020-10-03 Fuse programming
    [diyBMS-CurrentShunt.kicad_pcb, diyBMS-CurrentShunt.sch]
2020-10-04 Change connector pins
    [diyBMS-CurrentShunt.csv, diyBMS-CurrentShunt.kicad_pcb, diyBMS-CurrentShunt.sch]
2020-10-04 Added jumper connections
    [diyBMS-CurrentShunt.kicad_pcb, diyBMS-CurrentShunt.sch]
2020-10-04 Update diagram
    [diyBMS-CurrentShunt.kicad_pcb, diyBMS-CurrentShunt.sch]
2021-02-02 Step down converter
    [WBBOMDesign5.csv]
2021-02-02 Update shunt design to 5V and MAX4081SASA+
    [WBBOMDesign6.csv, diyBMS-CurrentShunt.kicad_pcb, diyBMS-CurrentShunt.sch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]
2021-02-22 LM5009 design and datasheets
    [WBBOMDesign11.csv, WBBOMDesign6.csv, WBOperatingValuesDesign11.csv]
2021-02-22 new design
    [CurrentShuntCircuit.kicad_pcb, CurrentShuntCircuit.sch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]
2021-02-23 PCB layout
    [CurrentShuntCircuit.csv, CurrentShuntCircuit.kicad_pcb, CurrentShuntCircuit.sch]
2021-02-24 First Gerbers
    [CurrentShuntCircuit-B_Cu.gbr, CurrentShuntCircuit-B_Mask.gbr, CurrentShuntCircuit-B_Paste.gbr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]
2021-02-24 Updated Gerber
    [CurrentShuntCircuit-B_Cu.gbr, CurrentShuntCircuit-B_Mask.gbr, CurrentShuntCircuit-B_Paste.gbr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]
2021-03-20 Increased hole clearance of screw sockets and labelled K on diodes
    [CurrentShuntCircuit.kicad_pcb]
2021-03-20 General board tidy up
    [CurrentShuntCircuit-B_Cu.gbr, CurrentShuntCircuit-B_Mask.gbr, CurrentShuntCircuit-B_Paste.gbr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]
2021-03-21 Tweak of traces on PCB, improve silkscreen layout
    [CurrentShuntCircuit.kicad_pcb, CurrentShuntCircuit.sch]
2021-03-21 Start of Current Monitoring Code ATTINY1614
2021-03-22 Label TXRX
    [CurrentShuntCircuit.kicad_pcb, CurrentShuntCircuit.sch]
2021-03-22 Initial test code, configure ports and basic i2c
2021-03-23 Tidy up tracks and positions - split VBUS into separate pin
    [CurrentShuntCircuit.kicad_pcb, CurrentShuntCircuit.sch]
2021-04-06 Swap to FastCRC library
    [SimpleModbusSlave.cpp, main.cpp, main.h]
2021-04-07 Swap to use DIP switch for config selection
    [CurrentShuntCircuit.kicad_pcb, CurrentShuntCircuit.sch]
2021-04-07 Flash Green LED on success data packets/commands
2021-04-07 Updated footprints
    [CurrentShuntCircuit.kicad_pcb, CurrentShuntCircuit.sch]
2021-04-07 Swap words for COMPILE_DATE_TIME_UTC_EPOCH
    [main.cpp]
2021-04-09 Silkscreen label 100V
    [CurrentShuntCircuit.kicad_pcb]
2021-04-30 Ordered from JLCPCB
    [CurrentShuntCircuit-B_Cu.gbr, CurrentShuntCircuit-B_Mask.gbr, CurrentShuntCircuit-B_Paste.gbr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]
2021-05-10 Automation of Gerber and documentation/BOM
    [CurrentShuntCircuit.kicad_pcb]
2021-05-10 CI: Generate gerbers and associated artifacts
    [CurrentShuntCircuit-bom.csv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]
2021-05-10 Remove files which are now auto generated
    [CurrentShuntCircuit-B_Cu.gbr, CurrentShuntCircuit-B_Mask.gbr, CurrentShuntCircuit-B_Paste.gbr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]
2021-05-10 Tidy up and change i2c pull ups to 4k7
    [CurrentShuntCircuit.kicad_pcb, CurrentShuntCircuit.sch]
2021-05-12 Fancy labels
    [CurrentShuntCircuit.kicad_pcb]
2021-05-13 Flash LED in case of errors
    [SimpleModbusSlave.cpp, main.cpp]
2021-05-14 Update JLCPCB code
    [CurrentShuntCircuit.sch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]
2021-06-08 Correct negative values in amp hour counting
    [main.cpp]
2021-06-09 Add mounting slot rather than holes
    [CurrentShuntCircuit.kicad_pcb]
2021-06-16 Fix 16 vs 32bit math
    [main.cpp]
2021-07-06 Increased hole cut out for larger shunt, resolve issue #2
    [CurrentShuntCircuit.kicad_pcb, mps_dpm_dc_shunt_200amps.step]
2021-08-19 Fix issue with resetting coulomb counter
    [main.cpp]
2022-11-19 Change CURRENT_LSB setting based on preferred values from TI calculation
2022-11-19 More tweaks to SoC on reboot
    [main.cpp, main.h]
2022-11-22 2.5% calibration change
2022-12-01 Remove shuntmv and current_lsb registers as they are meaningless to external apps - replaced with daily AH counter
    [main.cpp]
2022-12-05 Fix register mapping for daily AH counters
    [main.cpp]
2022-12-08 Dont reset daily counters on 100% SOC reset
    [main.cpp]
2023-01-25 Fix issue with two's complement on 20 bit registers (current)
    [main.cpp]
